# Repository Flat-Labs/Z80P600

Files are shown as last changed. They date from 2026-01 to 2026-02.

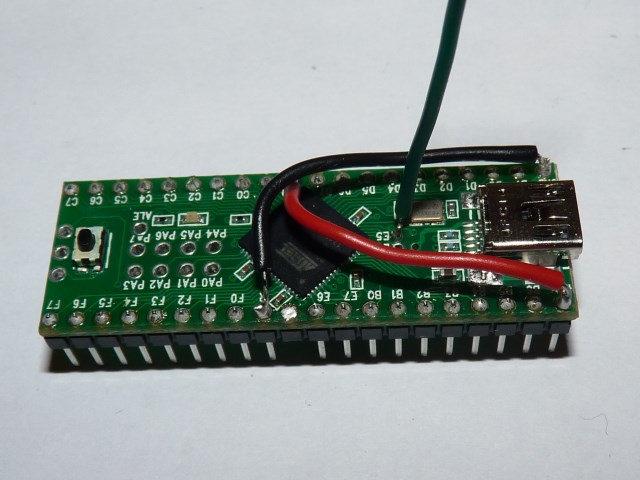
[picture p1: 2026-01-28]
documentation/pictures/4b_solder_wires.jpg

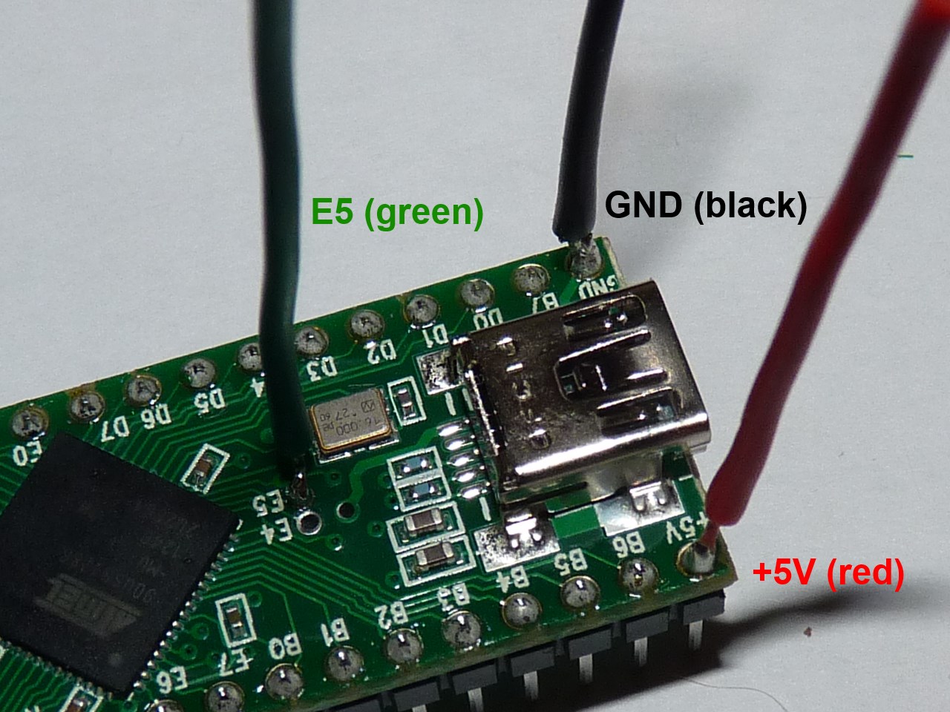
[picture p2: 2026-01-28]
documentation/pictures/2_solder_wires.jpg

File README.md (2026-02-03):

Z80P600
=======

A board and its firmware to replace (and enhance) the Z80 CPU of a SCI Prophet600.

Devised as a tribute to the amazing work of Gligli (http://gligli.github.io/p600fw/) and Imogen (https://github.com/image-et-son/p600fw),
it offers an alternative to Teensy board and its clones. 

Presets, settings, sequences and arpeggios are now stored on a separate F-RAM chip. Thus, all of these won't be lost during upgrades

The firmware functionalities are (almost) absolutely identical to the last Imogen's 2022 version, it only has been adapted to the new board. 
Please refer to the two above addresses for user manuals and informations.
I just added (Beta version) a misc command (From Tape + SEQ1) to wipe the settings out and set them to default . As tuning values are part of the settings, this obviously retunes the synth. 

Compiling and flashing the Firmware
===================================

Requirements:
- AVR-GCC toolchain
- avrdude uploader

For both these pieces of software on Windows, please refer to https://tinusaur.com/guides/avr-gcc-toolchain/.
A very clear and efficient guide to set up the toolchain. I used it with complete success on my windows box.

- python3 (https://www.python.org/downloads/)

- an USBASP programmer with six-pin header, such as this one (https://www.ebay.com/itm/116556456138) (Europe)
  or this one (https://www.ebay.com/itm/382191022734) (US)
  
Compiling:
----------
	> cd firmware
	> make

This will produce p600firmware.hex, which you can flash onto the board.

NOTE: As I'm not used to Github, I was unable to upload the dependence directory (.dep) in a correct manner. Therefore, there is a 'dep' directory in the firmare dir, that should be renamed to .dep for the make process to work.
Sorry for being a newbie here...

Flashing:
---------
1) For the first time.
	- Connect the Z80P600 board to the USBASP programmer (respect the 6-pins header pinout...)
	- Plug the USBASP into the PC
	- First, flash the fuses of the ATMEGA1281 (this has to be done only once, the first time):
	
		> avrdude -c usbasp -p m1281 -U lfuse:w:0x4f:m -U hfuse:w:0xdf:m -U efuse:w:0xf5:m -U lock:w:0xff:m
			
	- and flash the firmware:
	
		> avrdude -c usbasp -p m1281 -U flash:w:"p600firmware.hex":a
	
	To reflash a new version of firmware, only use the above avrdude command, as fuses have already been flashed.

	- Unplug the USBASP programmer of PC, disconnect the board, and plug it in the Z80 socket of P600
	- You're done ;)

2) Sysex upgrades 
	- Sysex upgrades work (From Tape + To Tape while powering on) and can be used to succesively upgrade the firmware through MIDI, provided that an older firmware has already been flashed once.

IMPORTANT NOTE : As the P600 presets, settings, sequences and arpeggios are now stored on a separate F-RAM, uploading (USBASP or sysex) a new firmware won't erase them.
Hence the option to reset the settings, just in case...

Board and PCB
=============

Schematics and PCB have been drawn using Kikad (V9 or above) : https://www.kicad.org/
The prototypes have been made (PCB + assembly) by JLC PCB, and the BOM file includes JLCPCB references for the parts.
The only part that is not included is the 40-pin DIL socket (Mouser ref. https://www.mouser.com/ProductDetail/437-1501064000106161 - gold plated, or https://www.mouser.com/ProductDetail/437-1508064000106101 - tinned), and it has to be hand-soldered.

Everything is working great, but the board LED seems a bit too bright for my taste...
So the R2 resitor value (for the LED) may be increased to something between 470 and 1000 ohms.

License
=======

Everything is under GPL v3 license, except files that have their own license in the header.

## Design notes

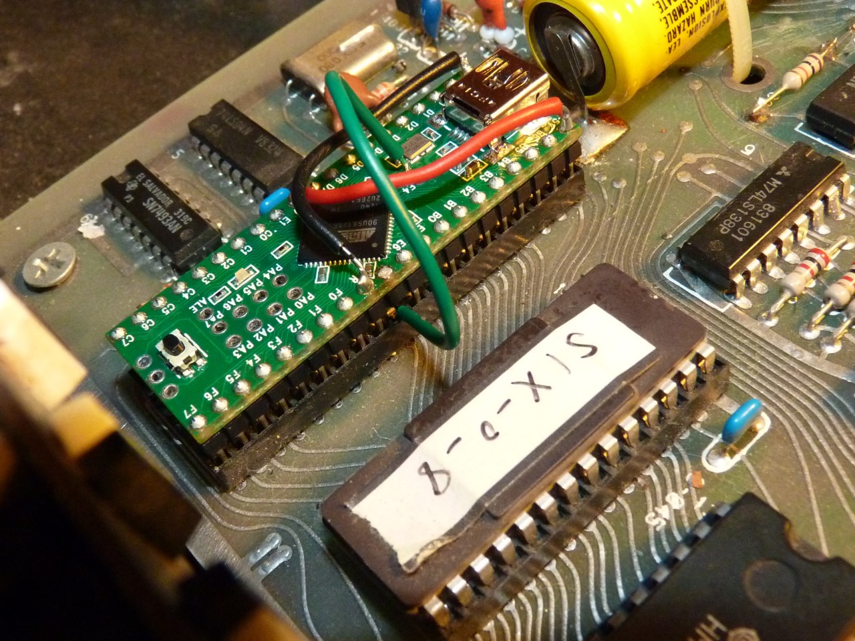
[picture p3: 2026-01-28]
documentation/pictures/6_plug_teensy.jpg

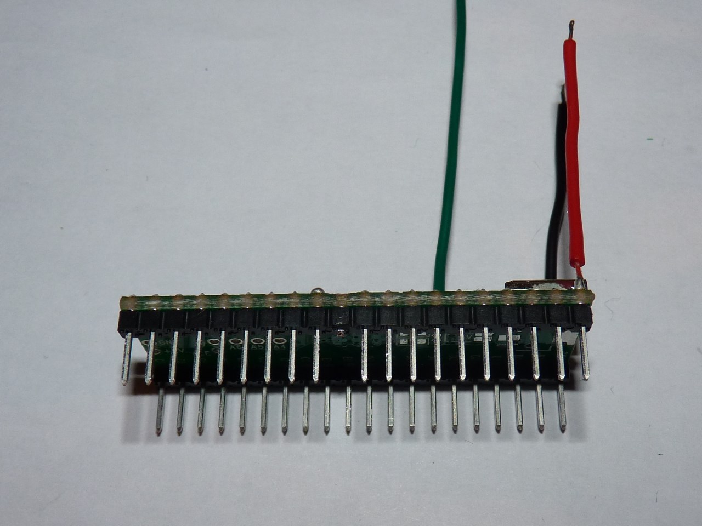
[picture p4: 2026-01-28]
documentation/pictures/3_cut_pin.jpg

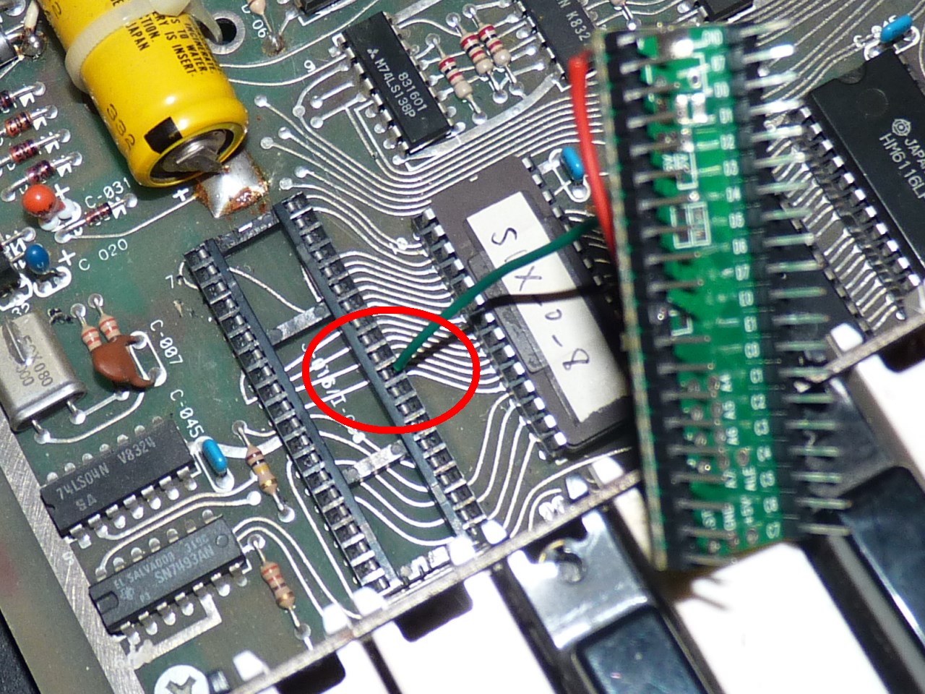
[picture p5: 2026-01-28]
documentation/pictures/5_plug_wire.jpg

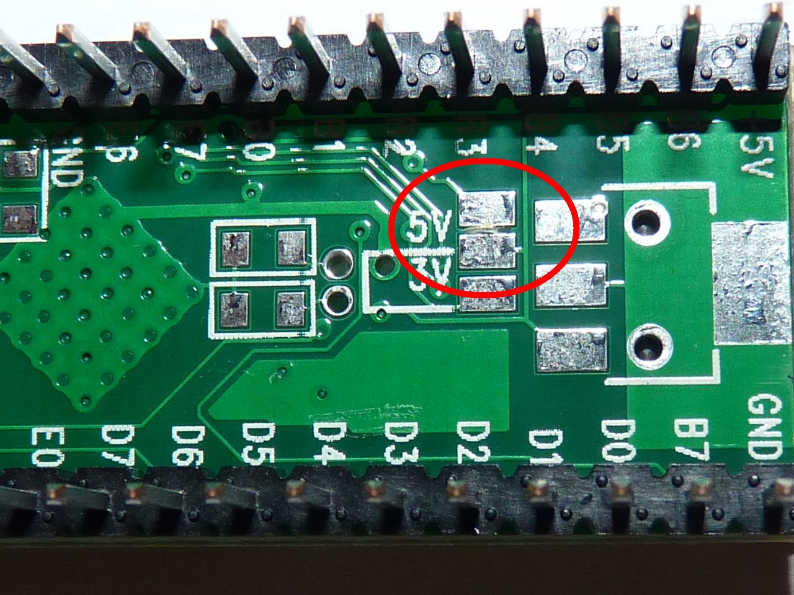
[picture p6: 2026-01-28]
documentation/pictures/1_cut_5v.jpg

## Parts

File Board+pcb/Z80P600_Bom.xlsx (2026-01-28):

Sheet: Feuil1
Reference | Qty | Value | DNP | Footprint
C1,C2,C3,C5,C6,C9,C10,C11,C13 | 9 | 100n |  | Capacitor_SMD:C_0402_1005Metric
C4 | 1 | 10n |  | Capacitor_SMD:C_0402_1005Metric
C7,C8 | 2 | 22p |  | Capacitor_SMD:C_0402_1005Metric
C12 | 1 | 4µ7 |  | Capacitor_SMD:C_0805_2012Metric
D1 | 1 | LED |  | LED_SMD:LED_0603_1608Metric_Pad1.05x0.95mm_HandSolder
J1 | 1 | ISP |  | Connector_PinHeader_2.54mm:PinHeader_2x03_P2.54mm_Vertical
R1 | 1 | 10K |  | Resistor_SMD:R_0402_1005Metric
R2 | 1 | 330 |  | Resistor_SMD:R_0402_1005Metric
SW1 | 1 | SW_MEC_5G |  | Button_Switch_SMD:SW_Push_1P1T-SH_NO_CK_KMR2xxG
U1 | 1 | FM25V05-G |  | Package_SO:SOIC-8_3.9x4.9mm_P1.27mm
U2 | 1 | TPS73633DBV |  | Package_TO_SOT_SMD:SOT-23-5
U3 | 1 | TXU0304RUT |  | Package_DFN_QFN:Texas_R-PUQFN-N12
U4 | 1 | ATmega1281-16A |  | Package_DFN_QFN:QFN-64-1EP_9x9mm_P0.5mm_EP7.65x7.65mm_ThermalVias
Y1 | 1 | 16MHz |  | Crystal:Crystal_SMD_2520-4Pin_2.5x2.0mm

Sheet: Sheet1
Comment | Designator | Footprint | JLCPCB Part #（optional）
100uF | C1 | CAP-SMD_L3.5-W2.8 | C16133
15K | R5,R6 | R0603 | C22809
DC-005-20A_C136744 | DC1 | DC-IN-TH_DC-005-20A | C136744
Header-Female-2.54_1x8 | P2,P3 | HDR-TH_8P-P2.54-V | C27438
K2-1102DP-C4SW-04 | SW1 | KEY-TH_4P-L6.0-W6.0-P4.50-LS6.5 | C110153
ATMEGA328P-PU | U1 | DIP-28_L34.6-W7.3-P2.54-LS10.2-BL | C33901
670688000 | USB1 | USB-B-TH_67068-8000 | C114097

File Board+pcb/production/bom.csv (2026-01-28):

Designator | Footprint | Quantity | Value | LCSC Part #
C1, C10, C11, C13, C2, C3, C5, C6, C9 | 0402 | 9 | 100n
C12 | 0805 | 1 | 4µ7
C4 | 0402 | 1 | 10n
C7, C8 | 0402 | 2 | 22p
D1 | 0603 | 1 | LED
J1 | PinHeader_2x03_P2.54mm_Vertical | 1 | ISP
R1 | 0402 | 1 | 10K
R2 | 0402 | 1 | 330
SW1 | SW_Push_1P1T-SH_NO_CK_KMR2xxG | 1 | SW_MEC_5G
U1 | SOIC-8_3.9x4.9mm_P1.27mm | 1 | FM25V05-G
U2 | SOT-23-5 | 1 | TPS73633DBV
U3 | Texas_R-PUQFN-N12 | 1 | TXU0304RUT
U4 | QFN-64-1EP_9x9mm_P0.5mm_EP7.65x7.65mm_ThermalVias | 1 | ATmega1281-16A
U5 | Z80_DIP-40_SMDSocket | 1 | Z80-Socket
Y1 | Crystal_SMD_2520-4Pin_2.5x2.0mm | 1 | 16MHz

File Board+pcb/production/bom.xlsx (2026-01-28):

Designator | Footprint | Quantity | Value | JLCPCB Part #
C1, C10, C11, C13, C2, C3, C5, C6, C9 | 402 | 9 | 100n | C71687
C12 | 805 | 1 | 4µ7 | C86040
C4 | 402 | 1 | 10n | C60133
C7, C8 | 402 | 2 | 22p | C106203
D1 | 603 | 1 | LED | C3030991
J1 | PinHeader_2x03_P2.54mm_Vertical | 1 | ISP | C225518
R1 | 402 | 1 | 10K | C60489
R2 | 402 | 1 | 330 | C313394
SW1 | SW_Push_1P1T-SH_NO_CK_KMR2xxG | 1 | SW_MEC_5G | C221678
U1 | SOIC-8_3.9x4.9mm_P1.27mm | 1 | FM25V05-G | C66025
U2 | SOT-23-5 | 1 | TPS73633DBV | C28038
U3 | Texas_R-PUQFN-N12 | 1 | TXU0304RUT | C2959768
U4 | QFN-64-1EP_9x9mm_P0.5mm_EP7.65x7.65mm_ThermalVias | 1 | ATmega1281-16A | C1337444
Y1 | Crystal_SMD_2520-4Pin_2.5x2.0mm | 1 | 16MHz | C255948

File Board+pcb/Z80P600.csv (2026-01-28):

Reference | Qty | Value | DNP | Exclude from BOM | Exclude from Board | Footprint | Datasheet
C1,C2,C3,C5,C6,C9,C10,C11,C13 | 9 | 100n |  |  |  | Capacitor_SMD:C_0402_1005Metric | ~
C4 | 1 | 10n |  |  |  | Capacitor_SMD:C_0402_1005Metric | ~
C7,C8 | 2 | 22p |  |  |  | Capacitor_SMD:C_0402_1005Metric | ~
C12 | 1 | 4µ7 |  |  |  | Capacitor_SMD:C_0805_2012Metric | ~
D1 | 1 | LED |  |  |  | LED_SMD:LED_0603_1608Metric_Pad1.05x0.95mm_HandSolder | ~
J1 | 1 | ISP |  |  |  | Connector_PinHeader_2.54mm:PinHeader_2x03_P2.54mm_Vertical | ~
R1 | 1 | 10K |  |  |  | Resistor_SMD:R_0402_1005Metric | ~
R2 | 1 | 330 |  |  |  | Resistor_SMD:R_0402_1005Metric | ~
SW1 | 1 | SW_MEC_5G |  |  |  | Button_Switch_SMD:SW_Push_1P1T-SH_NO_CK_KMR2xxG | ~
U1 | 1 | FM25V05-G |  |  |  | Package_SO:SOIC-8_3.9x4.9mm_P1.27mm | http://www.cypress.com/file/41651/download
U2 | 1 | TPS73633DBV |  |  |  | Package_TO_SOT_SMD:SOT-23-5 | http://www.ti.com/lit/ds/symlink/tps736.pdf
U3 | 1 | TXU0304RUT |  |  |  | Package_DFN_QFN:Texas_R-PUQFN-N12 | TXU0304PWR
U4 | 1 | ATmega1281-16A |  |  |  | Package_DFN_QFN:QFN-64-1EP_9x9mm_P0.5mm_EP7.65x7.65mm_ThermalVias | http://ww1.microchip.com/downloads/en/DeviceDoc/Atmel-2549-8-bit-AVR-Microcontroller-ATmega640-1280-1281-2560-2561_datasheet.pdf
U5 | 1 | Z80-Socket |  | Exclure de la Liste du Matériel |  | Z80P600:Z80_DIP-40_SMDSocket | www.zilog.com/manage_directlink.php?filepath=docs/z80/um0080
Y1 | 1 | 16MHz |  |  |  | Crystal:Crystal_SMD_2520-4Pin_2.5x2.0mm | ~

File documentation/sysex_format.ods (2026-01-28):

Overall SYSEX patch dump request format
Bit count | Value | Description
8 | 0xF0 | SYSEX header
24 | 0x00 0x61 0x16 | My vendor identifier
8 | 0x02 | Command code, “Patch dump request” here
8 | 0-99 | Patch number
8 | 0xF7 | SYSEX footer
Overall SYSEX patch dump format
Bit count | Value | Description
8 | 0xF0 | SYSEX header
24 | 0x00 0x61 0x16 | My vendor identifier
8 | 0x01 | Command code, “Patch dump” here
variable | variable | Encoded raw patch data, truncated to the last nonzero byte
8 | 0xF7 | SYSEX footer
Encoded data format (repeats every 32 bits of raw data)
Bit count | Value | Description
1 | 0 | Padding
7 | variable | Bits 30-24 of raw data (MSB first)
1 | 0 | Padding
7 | variable | Bits 22-16 of raw data (MSB first)
1 | 0 | Padding
7 | variable | Bits 14-8 of raw data (MSB first)
1 | 0 | Padding
7 | variable | Bits 6-0 of raw data (MSB first)
4 | 0 | Padding
1 | variable | Bit 7 of raw data
1 | variable | Bit 15 of raw data
1 | variable | Bit 23 of raw data
1 | variable | Bit 31 of raw data
Raw patch data format
Bit count | Value | Description
8 | 0-99 | Patch number
32 | 0xA5 0x16 0x61 0x00 | My patch format identifier
8 | 0x02 | My patch format version
16 | unsigned, little endian order | Osc A Frequency
16 | unsigned, little endian order | Osc A Volume
16 | unsigned, little endian order | Osc A Pulse Width
16 | unsigned, little endian order | Osc B Frequency
16 | unsigned, little endian order | Osc B Volume
16 | unsigned, little endian order | Osc B Pulse Width
16 | unsigned, centered on half scale, little endian order | Osc B Fine
16 | unsigned, little endian order | Cutoff
16 | unsigned, little endian order | Resonance
16 | unsigned, centered on half scale, little endian order | Filter Envelope Amount
16 | unsigned, little endian order | Filter Release
16 | unsigned, little endian order | Filter Sustain
16 | unsigned, little endian order | Filter Decay
16 | unsigned, little endian order | Filter Attack
16 | unsigned, little endian order | Amp Release
16 | unsigned, little endian order | Amp Sustain
16 | unsigned, little endian order | Amp Decay
16 | unsigned, little endian order | Amp Attack
16 | unsigned, centered on half scale, little endian order | Poly Mod Filter Amount
16 | unsigned, little endian order | Poly Mod Osc B Amount
16 | unsigned, little endian order | LFO Frequency
16 | unsigned, little endian order | LFO Amount
16 | unsigned, little endian order | Glide
16 | unsigned, little endian order | Amp Velocity
16 | unsigned, little endian order | Filter Velocity
7 | 0 | Padding
1 | bit (Off=0,On=1) | Osc A Saw
7 | 0 | Padding
1 | bit | Osc A Triangle
7 | 0 | Padding
1 | bit | Osc A Square
7 | 0 | Padding
1 | bit | Osc B Saw
7 | 0 | Padding
1 | bit | Osc B Triangle
7 | 0 | Padding
1 | bit | Osc B Sqr
7 | 0 | Padding
1 | bit | Sync
7 | 0 | Padding
1 | bit | Poly Mod Oscillator A Destination
7 | 0 | Padding
1 | bit | Poly Mod Filter Destination
5 | 0 | Padding
3 | Pulse=0,Tri=1,Rand=2,Sine=3,Noise=4,Saw=5 | LFO Shape
7 | 0 | Padding
1 | Low=0,High=1 | LFO Speed Range
2 | 0 | Padding
6 | None=0,VCO=1,VCF=2,VCA=4,PW=8,OnlyA=16,OnlyB=32 (combination of those) | LFO Mode Destination
6 | 0 | Padding
2 | None=0,Half=1,Full=2 | Keyboard Filter Tracking
7 | 0 | Padding
1 | Linear=0,Exponential=1 | Filter EG Exponential/Linear
7 | 0 | Padding
1 | Fast=0,Slow=1 | Filter EG Fast/Slow
7 | 0 | Padding
1 | Linear=0,Exponential=1 | Amp EG Exponential/Linear
7 | 0 | Padding
1 | Fast=0,Slow=1 | Amp EG Fast/Slow
7 | 0 | Padding
1 | bit | Unison
6 | 0 | Padding
2 | Last=0,Low=1,High=2 | Assigner Priority Mode
4 | 0 | Padding
4 | 2nd=2,3rd=5,5th=7,Octave=12 | Pitch bender semitones
6 | 0 | Padding
2 | Off=0,VCO=1,VCF=2,Volume=3 | Pitch bender target
5 | 0 | Padding
3 | Min=5,Low=3,High=1,Full=0 | Modulation wheel range
6 | 0 | Padding
2 | Free=0,Semitone=1,Octave=2 | Osc pitch mode
16 | unsigned, little endian order | Modulation delay
16 | unsigned, little endian order | Vibrato frequency
16 | unsigned, little endian order | Vibrato amount
16 | unsigned, little endian order | Unison detune
16 | unsigned, little endian order | Arpeggiator/sequencer clock
7 | 0 | Padding
1 | LFO=0,Vibrato=1 | Modulation wheel target
8 | 0 | Padding
6*8 | 6 offsets in semitones to the lowest chord note, 0xFF padded. Eg: 6 times 0x00 for unison, 0x00 plus 5 times 0xFF for mono mode. | Unison track pattern

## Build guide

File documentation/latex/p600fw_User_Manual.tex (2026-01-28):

%\documentclass[draft,landscape, 11pt, oneside]{report}
\documentclass[landscape, 11pt, oneside, twoside]{report}
\usepackage[a4paper, left=1cm, right=1cm, top=2.5cm]{geometry}
\usepackage{lmodern}
\usepackage{hyperref}
\usepackage{titlesec}
\usepackage{scrextend}
\usepackage{array}
\usepackage{ProphetPanel}
\usepackage{fontspec}
\usepackage[T1]{fontenc}
\usepackage{longtable}
\usepackage{ProphetTerms}
\usepackage{float}
\usepackage{setspace}
%\usepackage[inline]{showlabels}
\setmainfont[
 BoldFont={FiraSans-Bold}, 
 ItalicFont={FiraSans-Italic},
 ]{FiraSans}
\setlength{\parindent}{0pt}
\setlength{\parskip}{1em}
\setlength{\evensidemargin}{0cm}
\setlength{\oddsidemargin}{2cm}
\setlength{\paperheight}{210mm}
\setlength{\paperwidth}{297mm}
\setlength{\textwidth}{22cm}
\setlength{\footskip}{2.5cm}
%\input{defined_terms.tex}
\newenvironment{flowtext}{\addmargin[0cm]{0cm}}{\endaddmargin} % standard text width (reduced for layout)
\newcommand{\pp}[1]{} % patch parameter
\newcommand{\app}[2]{} % additional patch parameter, 1: number, 2: name

%%\title{[DRAFT] User Manual for the GliGli upgraded Prophet-600}
%%\pagestyle{myheadings}\markright{[DRAFT] User Manual for the GliGli upgraded Prophet-600}
%%\makeatletter
%%\renewcommand\chapter{\pagestyle{myheadings}\markright{[DRAFT] User Manual for the GliGli upgraded Prophet-600}\global\@topnum\z@\@afterindentfalse\secdef\@chapter\@schapter}
%%\makeatother
\titleformat{\chapter}[display]{\LARGE\bfseries}{}{0.0cm}{}
\titlespacing{\chapter}{0pt}{*0}{*0}
\titlespacing{\section}{0pt}{*0}{*0}

%%
%% Document Start
%%

\begin{document}

\raggedbottom
\singlespacing

\begin{titlepage}
\pagenumbering{gobble}

% this it the title "Prophet-600"
  \begin{tikzpicture}[scale=0.8]
    \begin{scope}[xslant=0.1]
        \SSGBit[1.5cm]{0,0}{12567}
        \SSGBit[1.5cm]{2.5cm,0}{57}
        \SSGBit[1.5cm]{5cm,0}{5734}
        \SSGBit[1.5cm]{7.5,0}{12567}
        \SSGBit[1.5cm]{10cm,0}{3567}
        \SSGBit[1.5cm]{12.5cm,0}{14567}
        \SSGBit[1.5cm]{15cm,0}{4567}
        \SSGBit[1.5cm]{17.5cm,0}{7}
        \SSGBit[1.5cm]{20cm,0}{134567}
        \SSGBit[1.5cm]{22.5cm,0}{123456}
        \SSGBit[1.5cm]{25cm,0}{123456}
      \end{scope}
  \end{tikzpicture}

  \vspace{1cm}

  \Huge
  User Manual \vspace{0.4cm} \\
  \Large
  Edition: version v2022 (8.8.2022) \vspace{0.3cm}\\
  Firmware version: GliGli \version by imogen\vspace{0.3cm}\\
  Editor / author: imogen / image-et-son 
  \normalsize

\end{titlepage}

\pagebreak
\pagebreak

%\maketitle
\tableofcontents

\pagestyle{myheadings}\markright{Prophet-600 \version User Manual }
\makeatletter
\renewcommand\chapter{\pagestyle{myheadings}\markright{Prophet-600 \version User Manual}\global\@topnum\z@\@afterindentfalse\secdef\@chapter\@schapter}
\makeatother

\pagebreak
\chapter{Introduction to the GliGli Prophet-600 Firmware Upgrade}

\pagenumbering{arabic}
\setcounter{page}{1}

\begin{flowtext}

The original Sequential Circuits Prophet-600 from around 1982 is run by a Zilog Z80 processor. This processor (and the firmware written for it) is pushed beyond its limits for computing and applying the voltages, for scanning user inputs and managing MIDI events. The necessary compromises made the instrument steppy, glitchy and non-responsive. That is a pity, because the basic synth voice hardware of the Prophet-600 is good: unlike DCO synths which became popular and affordable at the time, the Prophet-600 is a 6 voice analog synthesizer driven by 2 voltage controlled oscillators (VCOs) and a 24db low pass filter per voice, all implemented using the renowned Curtis chips \cite{curtis}. The hardware also provides hard sync, frequency modulation and even modulation of cut-off by VCO. It is very versatile. The shortcomings of the original Prophet-600 were due only to the unfortunate circumstance that the selected and commonly available micro-processors at the time were not powerful enough for the Prophet-600. So the idea to make use of a more modern processor 30 years later was interesting. Around 2013 GliGli \cite{gligli} started reverse engineering the original firmware for the Z80 and found that the Z80 can be replaced by a (more) modern Teensy++ 2.0 USB programmable microprocessor \cite{teensy} (with some hardware modifications). This was the start of what is now know as the \textit{Prophet-600 GliGli firmware upgrade}. GliGli describes his motivation as follows:

\begin{addmargin}[2cm]{1cm}

\textit{I love vintage analog synthesizers, and to be honest, my dream synth would be a Prophet-5, but when I heard what the Prophet-600 was capable of tone wise, I immediately thought its major weaknesses -- the lousy computer part, software envelopes and LFO -- could become its strength with a remake; basically the whole internal synth in voltage-controlled from a nice 14bit DAC, so with a fast modern micro controller, it could become awesome, maybe even better than a Prophet-5!}

\end{addmargin}

There are various modifications and modern CPU "implants" for some vintage analog synthesizers. Since the Teensy++ 2.0 board fits in to the same 2x20 pin standard socket of the Z80, the decisive advantage of the GliGli approach is that it is an easy-to-install and non-destructive firmware drop-in replacement\footnote{There are two versions of the Prophet-600. One has the Z80 on a socket. In this case replacement is truly "drop-in". The other version has the Z80 soldered to the circuit board. In this case the Z80 needs to be removed and a socket has to be soldered in its place first.}. It is completely safe to try out the Teensy++ 2.0 upgrade because one can always remove the board and restore the Z80 without technical expertise or training. 

The Teensy++ 2.0 offers completely new possibilities. Just looking at specs: the Z80 version of the Prophet-600 ran at 4 MHz while the ATMEL processor on the Teensy board is operated at 16 MHz. Also, the on-board flash memory provides much better storage and firmware handling possibilities compared to the EPROM which the Z80 uses. The firmware does not rely on a battery for keeping patch data in memory. With the replacement the obvious limitations of the original Prophet-600 could be overcome - but more than that, it opened the possibility for new and for enhanced features. 

Developing the software was a major effort with low-level functions and basic hardware communication at the core, e.g. instruction to set voltages to the electronic components, MIDI (interrupt) implementation, multiplexer operations and DAC operations. On top of this there is the "musical" part of coding such as envelopes, LFOs, modulations and sequencing functions as well as UI functions. Many people have contributed, most probably out of curiosity and passion for synthesizers and driven by the excitement that such a project could not only be conjured up but also be implemented and brought to life. 

The first stable version of the firmware upgrade was version 2.0 in 2014. An intermediate release (or at least something close to a release) version 2.1 Release Candidate 3 (2.1 RC3) has been available from September 5th 2015 on GliGli's webpages \cite{gligli}. The latest release version \version is the result of continued development between September 2021 and March 2022. It is meant as a celebration and revival of the original idea and it provides various new features and also significant improvements in core functions. The latest firmware version can be found on the project page\cite{newversion}.

While there is a realistic backlog of additional ideas to come in the future, there is a clear end of Prophet-600 upgrade story in sight because of ultimate hardware limitations. Firstly, PJRC (the manufacturer of the Teensy boards) has stopped producing the Teensy++ 2.0 board, so that it has become difficult to find them. Secondly, after extensive performance testing in the latest firmware developments efforts, it has become clear that the performance (smoothness and responsiveness of controls, timely and accurate processing of information) is finally limited by the built-in hardware, in particular the DAC (limited by voltage rise times) and multiplexer (limited by switching times). 

If you own a Teensy++ 2.0 upgraded Prophet-600 you can still enjoy some exciting new developments. The following is a compact summary of the improved and the new features. The manual generally refers to the latest version \version. Differences between versions are marked or commented in the text for your information. Share the passion for analog synthesizers with the Prophet-600 upgrade story!  

\begin{flushright}
  \textit{imogen / image-et-son}
\end{flushright}

\pagebreak
\section{What you can expect from the Firmware Upgrade}

\textbf{General features compared to the original Z80 version}
  
\begin{itemize}
  \setlength\itemsep{0cm}
  \item Greater resolution of many of the sound parameters with an improved refresh rate that makes the instrument much more responsive, again improved in \version using a dynamic scheme for reading user controls.
  \item Faster and smoother ADSR envelopes with support for two speed regimes (slow, fast) and two shapes (linear, exponential). The latest version \version has new linear shapes which were inspired by Prophet-5 rev 1/2 envelopes and designed to be more organic and musical than the former linear shapes.
  \item Positive and negative envelope amount settings for filter and poly-mod 
  \item A new LFO function generator with a wider frequency range from one cycle every 20 seconds to about 60Hz
  \item Assignable, random and up/down arpeggiator, optionally sync-able to external MIDI and analog clock
  \item Multiple note assignment modes including last/low/high note priority
  \item Full MIDI In control including amplitude and filter velocity sensitivity with an external keyboard controller, continuous controllers (CC) of all sound parameters, program change (PC) to choose current preset
  \item A dedicated vibrato which can be controlled by the modulation wheel
  \item Unison chord mode
  \item Four new LFO waveforms in addition to the original triangle and square including sine, random stepped, noise (like on the original Prophet-5, but non-periodic) and sawtooth (ramp up)
  \item Mix overdrive which now allows the output from both oscillators to drive the mix VCAs A and B harder as well as the Curtis 4 pole filter resulting in new sonic possibilities
  \item Pitch Wheel interval selection of plus/minus one octave, a whole tone, a minor third and a fifth
  \item Pitch Wheel reassignment to the VCF and Volume or off   
  \item Modulation wheel intensity setting in four steps, with a smooth (exponential) action in the latest version \version
  \item A new and improved tuning procedure
  \item Octave, chromatic and free oscillator course pitch control, with different options for oscillators A and B in the latest version \version
  \item Debounce feature that prevents unintended re-triggering caused by the old keyboard
\end{itemize}

\textbf{Specific features from version 2.1 RC3 onwards}
  
\begin{itemize}
  \setlength\itemsep{0cm}
  \item Polyphonic step sequencer
  \item Per note tuning
  \item Improved UI, introducing display of -50...50 range for bipolar dials and center deadband for better handling  
  \item VCF limit option
  \item Maintenance mode / adjustment scaling
  \item Vintage (spread) function for voice variations in tune and envelopes, re-designed as a continuous parameter in version \version which can even be controlled by MIDI CC   
  \item Support for pedal to sustain notes and to hold chords (in unison)
  \item On-the-fly transpose function for arpeggiator and sequencer
\end{itemize}

\textbf{Features with version \version}
  
\begin{itemize}
  \setlength\itemsep{0cm}
  \item Smoother and more responsive actions of all controls due to dynamic scanning scheme 
  \item Softer (exponential) action of LFO control (frequency and amount) to provide more travel for common "musical" value ranges
  \item Super accurate oscillator B fine tuning using a slow mid region
  \item Improved envelope shapes inspired by the Prophet-5 rev 1/2 shapes, replacing the linear shape in versions 2.0 and 2.1 RC3.  
  \item Revised and more intuitive organisation of menu parameters in groups with corresponding "cheat sheet"
  \item A new UI concept with pick-me-up behaviour, in order to avoid discontinuous value changes and to make the differences between panel and internal values transparent 
  \item Switchable panel layout with choices: Mix / Glide (Sequential Circuits / SCI layout)and Volume A / Volume B (synthgraphics supported GliGli layout) 
  \item Flexible envelope routing allowing the poly-mod to be modulated by either envelope generator
  \item Ability to sync the LFO to the arpeggiator and sequencer
  \item Better MIDI integration possibilities through new local off mode and MIDI input into sequencer and arpeggiator
  \item Improved and protected patch management via MIDI, supporting single patch dump and loading MIDI patch to active controls 
  \item Changed arpeggiator patterns: omitting the top and bottom note repeat in the U/D arpeggiator pattern and removing note repeats in the random pattern
  \item Support for adjusting the external CV input amount
  \item Vibrato target VCA
\end{itemize}

In addition to this, several more technical / advanced changes were made such as the option to switch between "round robin" and "first" voice assign logic, the ability toggle a pulse width sync bug which has been introduced in the version 2.0 (and kept for compatibility in version 2.1 RC3), changes to remove the interference  of internal and external (MIDI) pitch bend by adding the two (as in the original SCI firmware), stabilization of the external analog clock input.

\section{On compatibility for those upgrading from 2.0 and 2.1 RC3}

You can upgrade the firmware by SysEx or by directly loading the firmware onto the Teensy++ 2.0 board via USB (see section \ref{fwupgrade}). When upgrading by SysEx, both patch data and settings are preserved. Backward compatibility is ensured, i.e. patches created in prior firmware version (including Z80) still work properly on new firmware versions. Note that as a general principle, before performing any upgrade the safekeeping of patches is not only best practice but also strongly recommended. The following contains some remarks which are relevant if you are upgrading to version \version from version 2.0 or 2.1 RC3.

\textbf{Panel}: If you have a synthgraphics overlay, there are some minor changes (also reflected in the figures in this manual). Firstly, the layout of the menu parameters has been changed - these are now grouped in themes and since there are more parameters, selecting a parameter requires three presses in some cases. So the "cheat sheet" that some users have attached to the left of the number pad is not correct any more. Secondly (and less significant), what was formerly the "amplitude envelope" is now referred to more generally as the "2nd envelope". There are additional envelope routing options so that this envelope has a more generalized role. 

\textbf{Vintage / Spread}: With 2.1 RC3 a "spread" switch was introduced as part of the global settings (not part of the patch). With version \version this has been removed from the settings and has been reintroduced as the patch parameter \textit{vintage spread}. It serves the same purpose, but it can be controlled continuously and it is more randomized than the former spread switch for more realistic results.

\textbf{Detune}: The unison detune has undergone a scaling re-design in version \version: the detune is now less pronounced at higher frequencies. This has been done to achieve the same subjective detuning effect across the whole frequency range. This is a change to the sound of the instrument and depending on how you use detune, your detuned unison patches may sound slightly different at higher registers compared to prior firmware versions. The idea is of course, that this is an agreeable change for everybody.

\textbf{Arpeggiator}: The arpeggiator patterns up/down and random have been changed in version \version

\textbf{MIDI CC}: Due to the change in menu parameters (obsolete parameters) and subsequent reshuffling (re-designation of the CC values for the legacy LFO frequency range), the specification of MIDI CC has changed slightly. As a result of rescaling of parameters the MIDI CC value to action has changed for LFO and vibrato frequencies and LFO and vibrato amounts as well as decay and release times of envelopes with linear shape. When loading older patches, the changes are taken into account to ensure compatibility.

\textbf{Envelopes}: The linear envelope shape has been revised in version \version. It is now a linear shape with an exponential tail (i.e. a softer roll-off) for decay and release. It was a deliberate decision to replace the linear shape altogether. Note that the smooth roll-off required a rescaling of the envelope decay and release controls for linear shapes. When loading older patches, the changes are taken into account to ensure compatibility: the effective decay and release times are preserved. However, the application of MIDI CC values is different, so if you are controlling sound by MIDI CC you may need to make adjustments.

\section{Credits and license}

The firmware upgrade project is an open source project. The GliGli code base (up to and including version 2.1 RC3) can be found in \cite{gligli} and the new code base of the latest development can be found in \cite{imogen}. When I first drafted this manual I hoped to put together a credits section by assembling a fair and comprehensive list of contributors. I have given up. There was no one who could, with authority, list and assess what came from where and who added what. From my research I can say that a \textbf{lot} of people have contributed and some have obviously spent considerable time to make this software as useful and consistent as possible. 

Let me just give you some highlights and a brief roundup. First, I think that the original 77 page technical documentation of the Prophet-600 by Stanley Jungleib \cite{p600siservicemanual} is great and such  documentation is both helpful and more than one can expect. Then there is an elaborate blog "Prophet-600 Spirit" by \textit{minisystem} \cite{p600spirit} which is legacy by now but still available. It contains a lot more technical information, Prophet-600 hardware related ground work, I would call it. I had the impression that it also helped the project. The contributors to the actual code can be obtained from the submit history of the code base on Github \cite{imogen}. Apart from GliGli (obviously) I found \textit{snickell} and \textit{Ricard Wanderlof} with many commits, although I haven't taken the time to disseminate their contributions in detail. Then there is the community, especially (but certainly not exclusively) on Gearspace (a common community platform for people to discuss music gear, not so long ago also known as Gearslutz): testing, giving feedback, spreading the word, supporting the project by appreciation and enthusiasm. Since I started picking up the development in November 2021 I joined up with a group of supporters and musicians loosely bound together by a forum thread on Gearspace. A number of active users have been especially helpful in prioritizing features, testing and proof reading. I neither want to list all of them, nor single someone out. Let me just say that developing the new envelopes and experimenting with different and sometimes really tricky aspects of the Prophet-600 hardware (e.g. multiplexers) would have been a lot less fun (and in parts even impossible) without an active community and dedicated co-workers.  

This user manual contains some texts and snippets written by other people. I compiled, merged, extended and in some case corrected the available information to an extent that makes it near impossible to trace everything back to its origins, let alone put in proper references. I just assume that all consent to the usage of their words. The overwhelming part of the text and the graphics are new.

The firmware  is under GPL v3 license, except files / libraries / other open source components that have their own license in the header. The usage of the software and related documentation (including descriptions and references to descriptions for making modifications to hardware) are understood to be at the user's own risk. The firmware program is distributed in the hope that it will be useful, but WITHOUT ANY WARRANTY; without even the implied warranty of MERCHANTABILITY or FITNESS FOR A PARTICULAR PURPOSE. See the GNU General Public License for more details.

\end{flowtext}

\pagebreak

\chapter{Finding your way around your new  Prophet-600}    

\begin{flowtext}

The different controls and interfaces of the Prophet-600 are shown schematically below. Throughout the document the corresponding nomenclature is used. In the original GliGli firmware upgrade the dials for oscillator A vs. B mix had been replaced by separate dials for oscillator A volume and oscillator B volume, at the expense of demoting the glide amount to a menu parameter. In the newest firmware version you have the choice to either use the \textit{GliGli} layout or the original \textit{Sequential Circuits (SCI)} layout. For more details on how to change the panel and on the parameters in each case see section \ref{panelswitch}.

\begin{samepage}
  \textbf{GliGli panel layout (like synthgraphics overlay)}
  
  \nopagebreak
  \scalebox{0.2}{
    \begin{tikzpicture}[scale=0.8]
      \input{full_panel_gligli.tex}
    \end{tikzpicture}
  }
\end{samepage}

\begin{samepage}

  \textbf{Sequential Circuits panel layout}
  
  \nopagebreak
  \scalebox{0.2}{
    \begin{tikzpicture}[scale=0.8]
      \input{full_panel_sci.tex}
    \end{tikzpicture}
  }
\end{samepage}

The following sections contain a brief explanation of the controls and interfaces: the \textbf{Rear}, \textbf{Data Pad}, \textbf{Panel} (with sub-panels), \textbf{Performance Section} and \textbf{Keyboard}.

\section{Data Pad and basic operation}\label{datapad}

The \datapad consists of the \display (2 two digit 7 segment display with one dot\footnote{The were good ideas for using a second display dot to make the UI more sophisticated, but - unfortunately - even though the display has the second dot, the Prophet-600 hardware supports control of only one dot.}), the \termnumberpad, the \funcbuttons and the \datadial. 

\textbf{Function Buttons}

The block of 9 \funcbuttons is the main control from where you activate and toggle the operation modes and functions of the Prophet-600. This block consists of an upper part (controlling essential functions) and a block of buttons relevant for the sequencer and arpeggiator, as shown below. (The \record button has a function of both.)

\scalebox{0.4}{
  \begin{tikzpicture}[scale=0.8]
  \node[font=\fontsize{26}{22}\selectfont, align=right, outer sep=0.5mm, anchor = west, text width=10cm] at (0cm,12cm) {Upper block of Function Buttons:};
    \upperbuttons{15cm,7cm}{P}{}
  \node[font=\fontsize{26}{22}\selectfont, align=right, outer sep=0.5mm, anchor = west, text width=10cm] at (30cm,12cm) {Buttons relevant for sequencer and arpeggiator:};
    \arpsqbuttons{45cm, 9cm}{R1}{1}
  \end{tikzpicture}
}

The \funcbuttons have LEDs which can be off, be on solid and on blinking. In the entire document the following convention for representing the button LED status off / on / blinking is used.

\scalebox{0.4}{
  \begin{tikzpicture}[scale=0.8]
  \node[font=\fontsize{26}{22}\selectfont, align=left, outer sep=0.5mm, anchor = west] at (0cm,2.5cm) {LED \\ Status:};
  \prophetledbutton[1cm]{10cm, 2.5cm}{RECORD}{R}{}{R}
  \node[font=\fontsize{26}{22}\selectfont, align=left, outer sep=0.5mm, anchor = west] at (11.5cm,2.5cm) {= LED on solid};
  \prophetledbutton[1cm]{25cm, 2.5cm}{RECORD}{R}{R}{R}
  \node[font=\fontsize{26}{22}\selectfont, align=left, outer sep=0.5mm, anchor = west] at (26.5cm,2.5cm) {= LED on blinking};
  \prophetledbutton[1cm]{40cm, 2.5cm}{RECORD}{}{}{R}
  \node[font=\fontsize{26}{22}\selectfont, align=left, outer sep=0.5mm, anchor = west] at (41.5cm,2.5cm) {= LED off};
  \end{tikzpicture}
}

The different functions of the buttons are described in the general modes description in section \ref{uimode}, and throughout the chapter \ref{function} in the context of specific functions in which they are used.

\textbf{Number Pad}

This pad has three usages depending on mode and selected functions:

\begin{itemize}
  \item Selecting a patch number from one of the internal 100 patch storage slots to load in \presetpatch  (see section \ref{uimode})
  \item Selecting a patch number for storing a patch to one of the internal 100 patch storage slots in \storagemode (see section \ref{loadstorepatches})
  \item Selecting a patch number to export a patch as MIDI SysEx in \patchmgmt (see section \ref{patchmgmt})
  \item Selecting a function / setting in \shiftmode and \shiftlock (see miscellaneous settings below and overview in section \ref{settingsref})  
  \item Selecting a parameter in the additional patch parameter menu (see section \ref{app}) in \presetpanel and in \livemode
\end{itemize} 

\pagebreak

\textbf{Display}

\input{display.tex}

\pagebreak

\textbf{Preset panel mode, live mode and additional patch parameters menu}\label{app}

The Prophet-600 operates in two modes, \presetmode and \livemode, see section \ref{uimode}. The mode of operation determines what the display shows and what functions are invoked when you press the number pad buttons, as shown in the table below.

\scalebox{0.4}{
  \begin{tikzpicture}[scale=0.8]
    \node[font=\fontsize{26}{22}\selectfont, align=left, outer sep=0.5mm, anchor = west] at (-8cm,13cm) {Basic modes:};

    \draw[line width=1pt]++(-6cm,-7.5cm)--++(55cm,0cm);  
    \draw[line width=1pt]++(-6cm,-5cm)--++(55cm,0cm);  
    \draw[line width=1pt]++(-6cm,-3cm)--++(55cm,0cm);  
    \draw[line width=1pt]++(-6cm,-1cm)--++(55cm,0cm);  
    \draw[line width=1pt]++(-6cm,9.5cm)--++(55cm,0cm);  

    \node[font=\fontsize{26}{22}\selectfont, align=left, outer sep=0.0mm, anchor = west, text width=12cm] at (-6cm,5cm) {LED};
    \node[font=\fontsize{26}{22}\selectfont, align=left, outer sep=0.0mm, anchor = west, text width=12cm] at (-6cm,-2cm) {Display};
    \node[font=\fontsize{26}{22}\selectfont, align=left, outer sep=0.0mm, anchor = west, text width=12cm] at (-6cm,-4cm) {Number pad};
    \node[font=\fontsize{26}{22}\selectfont, align=left, outer sep=0.0mm, anchor = west, text width=12cm] at (-6cm,-6.5cm) {Enter / leave};

    \node[font=\fontsize{26}{22}\selectfont, outer sep=0.0mm, anchor = south west, text centered, text width=12cm] at (4cm,10cm) {\livemode};
    \node[font=\fontsize{26}{22}\selectfont, outer sep=0.0mm, anchor = south west, text centered, text width=12cm] at (19.2cm,10cm) {\presetpatch};
    \node[font=\fontsize{26}{22}\selectfont, outer sep=0.0mm, anchor = south west, text centered, text width=12cm] at (34.2cm,10cm) {\presetpanel};

    \node[font=\fontsize{18}{22}\selectfont, outer sep=0.0mm, anchor = west, text centered, text width=12cm] at (4cm,-2cm) {Parameter values};
    \node[font=\fontsize{18}{22}\selectfont, outer sep=0.0mm, anchor = west, text centered, text width=12cm] at (19.2cm,-2cm) {Patch number};
    \node[font=\fontsize{18}{22}\selectfont, outer sep=0.0mm, anchor = west, text centered, text width=12cm] at (34.4cm,-2cm) {Parameter values};

    \node[font=\fontsize{18}{22}\selectfont, outer sep=0.0mm, anchor = west, text centered, text width=12cm] at (4cm,-4cm) {Select add. parameter};
    \node[font=\fontsize{18}{22}\selectfont, outer sep=0.0mm, anchor = west, text centered, text width=12cm] at (19.2cm,-4cm) {Select patch};
    \node[font=\fontsize{18}{22}\selectfont, outer sep=0.0mm, anchor = west, text centered, text width=12cm] at (34.4cm,-4cm) {Select add. parameter};

    \node[font=\fontsize{18}{22}\selectfont, outer sep=0.0mm, anchor = west, text centered, text width=12cm] at (4cm,-6.25cm) {From \preset using \preset button};
    \node[font=\fontsize{18}{22}\selectfont, outer sep=0.0mm, anchor = west, text centered, text width=12cm] at (19.2cm,-6.25cm) {From \livemode using \preset, from \presetpanel mode using \totape};
    \node[font=\fontsize{18}{22}\selectfont, outer sep=0.0mm, anchor = west, text centered, text width=12cm] at (34.4cm,-6.25cm) {From \presetpatch mode using \totape};

    \upperbuttons{6cm, -0.5cm}{}{}   
    \upperbuttons{21cm, -0.5cm}{P}{}   
    \upperbuttons{36cm, -0.5cm}{PT}{}   
    \draw[line width=1pt]++(4cm,-7.5cm)--++(0cm,19cm);  
    \draw[line width=1pt]++(19.2cm,-7.5cm)--++(0cm,19cm);  
    \draw[line width=1pt]++(34.4cm,-7.5cm)--++(0cm,19cm);  
  \end{tikzpicture}
}

The following section describes how patch parameters are accessed and modified in live mode and in \presetpanel. Patch parameters are - by definition - stored, exported and loaded per patch. Most patch parameters can be controlled using dials and switches on the panel (see section \ref{panel}). With the firmware upgrade the Prophet-600 provides a range of \textbf{Additional Patch Parameters}. There are \textit{continuous} parameters (numeric) and \textit{stepped} parameters (select options). Changing these parameters can only be done in \presetpanel or in \livemode. You must select the parameter first and then change the value using the \datadial. A parameter is selected by pressing the buttons 0...9 on the \termnumberpad (or pressing them twice or in some cases three times). If you select a new parameter, the respective parameter name is scrolled through the display. The display then shows the current value. Numeric values are shown permanently and choice settings are scrolled through the display. 

Each parameter is explained in the respective functional context in the next chapter. For a quick reference of additional patch parameters please see section \ref{patchref}. 

Note 1: The parameter accessed using the number 0 is an exception. The parameter \clock controls the internal sequencer and arpeggiator speed or external clock divide and this speed is stored as an instrument setting (see next section) and not as a patch parameter. For details on \clock see \ref{sync}.

\textbf{Shift mode and miscellaneous settings}

The \miscsett are patch independent instrument settings and functions. These settings are stored and re-loaded after a power cycle. The miscellaneous settings are accessed via the \termnumberpad in \shiftmode. To activate this mode either hold down the button \fromtape while selecting one of the additional functions or double press \fromtape to enter \shiftlock (permanent shift) indicated by a blinking \fromtape LED. To exit the mode push the button again. 

In \shiftmode the numbers 0...9 on the \termnumberpad as well as some of the function buttons let you access the \miscsett. The settings are edited by pressing the respective buttons repeatedly to cycle through values or to initiate actions. The first time a button is pressed the display scrolls the current value or mode. Pressing the same number key again cycles through the values of that setting or confirms a certain action or mode change. 

Some important functions which you access in \shiftmode and \shiftlock are ...
\begin{itemize}
  \item ... the numbers 0...9 access MIDI setup, voice (de-)activation, panel layout, pitch bender calibration, panel layout switch, etc. 
  \item ... the keys on the keyboard are used to set the keyboard transposition (see section \ref{transposition}) 
  \item ... the \tune button activates the \pernote  (see section \ref{tuning}).
  \item ... pressing the \record button activates the \patchmgmt (see section \ref{patchmgmt})
  \item ... pressing the \preset (and confirmation) loads the default patch (see section \ref{defaultpatch})
\end{itemize}

The list of miscellaneous settings can be found in section \ref{settingsref}. Each setting is explained in the respective functional context in the chapter \ref{function} and in the chapter \ref{maintenance} on instrument setup tasks.

\section{Panel}\label{panel}

Two slightly different panel layouts are supported. In \textit{SCI} layout the panel is organized in 6 sub-panels, 3 additional patch controls (\unison, \mixer and \glidepot) plus two global controls, \mastertune and \mastervol. In \textit{GliGli} layout the panel is organized in 7 sub-panels (an additional mixer sub-panel), the patch parameter \unison and the two global controls \mastertune and \mastervol. 

\begin{itemize}
  \item Poly-Mod sub-panel (see section \ref{polymod})
  \item LFO sub-panel (see section \ref{lfo})
  \item Oscillator A sub-panel (see section \ref{osc})
  \item Oscillator B sub-panel (see section \ref{osc})
  \item Mixer sub-panel (in GliGli panel layout only, see section \ref{osc}).  
  \item Filter sub-panel (see section \ref{filter} and \ref{envelopes}) 
  \item 2nd Envelope sub-panel (see section \ref{envelopes})
  \item Unison switch (see section \ref{poly-unison-voice})
  \item Mix dial (in Sequential Circuits panel layout only, see section \ref{osc})
  \item Glide dial (in Sequential Circuits panel layout only, see section \ref{glide})
\end{itemize}

These controls are all patch parameters, which means they are stored, loaded, imported and exported with a patch. The panel controls \mastertune and \mastervol to the very right of the panel are not part of the patch. These controls are always applied as they are. They are meant to adjust the instrument to the performance environment (e.g. spontaneous tuning to a band/ensemble and adjustment of the volume). Also, you can always reliably start the instrument with volume turned to zero.

\section{Keyboard and performance section}

Without modifications, the Prophet-600 comes with a non-weighted, 5 octave (61 key) keyboard. The keyboard does not support touch sensitivity (although the upgraded Prophet-600 supports velocity sensitivity for amplitude and filter via MIDI, see section \ref{velocity}). Apart from playing, the keyboard is used for arpeggiator and sequencer input (see section \ref{seq}) and for transposition (see section \ref{transposition}). 

The Prophet-600 offers a \pitchbender (unfortunately without a spring mechanism) and a \modwheel. The mid position of \pitchbender can be calibrated and there are several different bend targets to choose from, see section section \ref{pitchbend}. You can adjust the effect strength or action profile of the modulation wheel, and you choose if it should modulate the LFO or the vibrato, see section \ref{modwheel}.

\section{Rear, inputs and output}

\input{rear.tex}

\section{The concept}

With the clearly laid out panel controls the Prophet-600 is both, a hands-on performance instrument and a sound sculpting synthesizer at the same time. The upgrade preserves that basic character. The controls on the panel have largely the same function as in original. 

However, the new functionalities of the upgrade required additional parameters and these had to be placed in new hidden menus. This has obvious disadvantages. Diving into menus interrupts the work flow. It is abstract and unsatisfying. It is only acceptable for parameters which are rarely used and certainly not suited for live tweaking. 

Another important aspect is the preservation of the general user interface concept. In particular, for each function there should be a unique way to do it, not a mix of say, dials and menus. This is one reason why the upgrade also contains "only" one LFO and two envelopes even though one might have added more with the new processor. This corresponds to the layout of the Prophet-600 and anything more would have meant at least a partial dive into menus. There are some notable exceptions, such as the LFO shape, which is a mix of flipping a switch on the control panel and choosing options in the additional patch parameter menu. In most cases an additional patch parameter either has completely separate function form what is available on the control panel (such as the vibrato, which is fully controlled by menu parameters) or it had the function to modify the panel control behavior (such as envelope ranges, etc.). 

A useful work flow of the upgraded Prophet-600 for creating or editing patches could be as follows:

\begin{enumerate}
  \item Pre-production: set basic overall patch parameters, such as envelope shapes and routing, LFO targets and shape
  \item Production: use the panel controls to interactively design the sound 
  \item Post-production: add additional features, such as vibrato, bend modulation, spread, etc. for a final touch
\end{enumerate} 

Ideally, menu diving should be largely restricted to steps 1 and 3 so that uninterrupted hands-on and interactive work with the synthesizer is possible in step 2. 

\pagebreak
\chapter{Functionality}\label{function}

\section{Operating modes: preset and live mode}\label{uimode}

\input{uimode.tex}

\section{Loading and storing patches}\label{loadstorepatches}

\input{loadstorepatches}

\section{Oscillators and mix}\label{osc}

\input{osc.tex}

\pagebreak

\section{Volume and master tune}

To the right of the panel there are two global controls, \mastertune and \mastervol. The master tuning has a range of approximately $\pm 1$ semitone. Its purpose is to be able to tune the synth to other instruments without touching the internal, relative frequencies of the oscillators and thereby potentially changing the patch.

\mastervol and \mastertune are neither patch parameters nor settings. The two values are applied as set on the panel. The only exception is external MIDI control of volume (see section \ref{midiimplementation}). When the master volume is set via MIDI CC that volume level continues to be applied until either a new value is set by MIDI or until the \mastervol control is touched/changed. 

After power-up the instrument volume is always set to the value position of the \mastervol control.

\section{Filter}\label{filter}

\input{filter.tex}

\section{Envelopes and routing}\label{envelopes}

\input{envelopes.tex}

\section{Polyphonic, unison and chord mode, voice assigner priority}\label{poly-unison-voice}

\input{poly-unison-voice.tex}

\section{LFO}\label{lfo}

\input{lfo.tex}

\section{Poly-mod and oscillator sync}\label{polymod}

\input{polymod.tex}

\pagebreak

\section{Arpeggiator / sequencer clock and MIDI support}\label{sync}

The Prophet-600 offers a polyphonic sequencer with two tracks and an arpeggiator with three distinct pattern types. The details of operation are explained in sections \ref{arp} (arpeggiator) and \ref{seq} (sequencer).

The sequencer and arpeggiator share the same clock, which can simultaneously run both sequencer tracks and one arpeggiator pattern. In order to be able to operate the sequencer and/or arpeggiator in sync with other instruments, the upgraded Prophet-600 provides three different clock source methods which are configured in the miscellaneous setting \clocksync.
\begin{itemize}
  \item \textit{internal}: the internal clock is used. The \clock is edited like a menu patch parameter associated with number 0
  \item \textit{MIDI}: the clock is synced to the MIDI clocked received on the MIDI receive channel as set in the  miscellaneous settings
  \item \textit{tape}: the clock is synced to a fraction of a pulse clock received via the Tape In input on the rear of the instrument. 
\end{itemize}  
When the clock source is set to external (either \textit{MIDI} or \textit{tape}) the \clock sets the clock divide. The values are: 192,168,144,128,96,72,48,36,24,18,12,9,6,4,3,2.

It is also possible to sync the LFO to the sequencer / arpeggiator clock (internal or external). The menu parameter \lfosync provides the options \textit{off} (no sync, free running LFO) or one of the following \textit{1,2,3,4,5,6,8}. The latter sets the number of clock beats after which the LFO in reset.

Note that you can also operate the sequencer and/or arpeggiator in unison mode with all features of that mode (see section \ref{poly-unison-voice}). However, the voices are not shared between the tracks and the arpeggiator. The priority is as follows: arpeggiator, sequencer track 2, sequencer track 1. If activated, the arpeggiator will use all voices in unison mode and when the sequencer tracks 1 and 2 have a note on the same beat, only track 2 will play. Unison mode should be activated before starting the sequencer or arpeggiator.

\pagebreak

\section{Arpeggiator}\label{arp}

\input{arp.tex}

\pagebreak

\section{Sequencer}\label{seq}

\input{seq.tex}

\section{Vibrato}\label{vib}

\input{vibrato.tex}

\section{Pitch bender}\label{pitchbend}

\input{pitchbend.tex}

\section{Modulation wheel and modulation delay}\label{modwheel}

\input{modwheel.tex}

\section{Glide}\label{glide}

The Prophet-600 offers a glide function in polyphonic and unison mode. Generally speaking, the glide time determines the how fast the pitch glides from the start note to the target (played) note. Glide is based on voice, i.e. once a note is assigned to a voice the glide start note will be the last note of that voice (rather than, for example, the last played note). 

The way you set the glide time depends on the current active panel layout. When the panel layout is set to \textit{GliGli} you must use the menu parameter \glide to set the glide time. When the panel layout is set to \textit{SCI}, the menu parameter \glide is suppressed and the glide time is set by the \glidepot dial instead. 

For details on the panel layout options see section \ref{panelswitch}. 

Note that since glide is voice based, the voice assignment logic (as set using the parameter \assign, see \ref{poly-unison-voice}) has a strong impact on the behaviour of glide in polyphonic mode. The voice assignment logic determines the glide start note once a new note is played.

\section{Detune}\label{detune}

The upgraded Prophet-600 provides a method to detune the 6 voices against one another. This effect is used to make unison sounds broader and more lively. Detune is only applied when unison is activated. The menu parameter for setting detune is \detune. Note: the effect of the vintage spread (see section \ref{spreadsett}) is applied in all modes and is therefore added to detune in unison mode. 

The detune functions has been changed in version \version. Compared to versions 2.0 and 2.1 RC3 the detune is scaled with pitch is less pronounced for higher pitches. This change is designed such that the perceived detune is constant (or at least more constant) over the available pitch range. 

\section{Vintage / spread}\label{spreadsett}

\input{spread.tex}

\section{External CV in}\label{extcv}

The Prophet-600 offers the option to control the filter cut-off frequency using an external voltage source fed into the Prophet-600 via the \textbf{Filter CV In} plug on the rear panel. Applying a voltage to that input raises the filter cut-off frequency.

In the upgraded Prophet-600 the strength of the external CV input effect can be controlled using the menu parameter \extvolt. The parameter has been newly introduced in version \version. In versions 2.0 and 2.1 RC3 the external CV control strength is fixed and it is set to maximum by default. In the new version on the other hand the patch parameter value is zero and it therefore needs to be changed before using the external voltage control. 

One application of the external voltage control is that it is used in the popular "noise mod" of the Prophet-600 and in this mod the parameter controls the level of an additional noise source. 

\section{Velocity sensitivity}\label{velocity}

The Prophet-600 is equipped with a non-weighted keyboard without support for velocity. However, when played via MIDI, the upgraded Prophet-600 supports velocity sensitivity of amplitude and filter cut-off frequency. The respective velocity amounts are configured using the two menu parameters \ampvel and \filvel.

By default the \ampvel is set to half-way and the \filvel is set to zero. Amplitude and filter velocity are not supported in arpeggiator and sequencer.

\pagebreak

\chapter{Synthesizer setup and maintenance}\label{maintenance}

\section{Tuning}\label{tuning}

\input{tuning.tex}

\section{Switchable panel layout}\label{panelswitch}

\input{panelswitch.tex}

\section{MIDI integration}\label{midiintegration}

\input{midiintegration.tex}

\section{Voice deactivation}\label{voices}

The upgraded Prophet-600 provides a method for switching single voices off. This can be useful to suppress a voice that is damaged or for troubleshooting, e.g. isolating voices for testing. The "voice masking" is configured using the miscellaneous settings with \numberbut{4} and \numberbut{5} in \shiftmode or \shiftlock as follows
\begin{enumerate}
  \setlength\itemsep{0cm}
  \item Press \numberbut{4} to cycle through the 6 voice of the Prophet-600. This selection determines the functionality of the key \numberbut{5} in the setting menu.
  \item Press \numberbut{5} to toggle between on and off of the voice selected using \numberbut{4}. 
\end{enumerate}

Note: the voice masking is stored in the settings. It therefore applies to all patches and all modes and it is retained through a power cycle. If you are missing a voice you should check the voice masking.

\section{Transposition}\label{transposition}

In the upgraded Prophet-600 there are two types of transposition which you set in the same way. The first one is the transposition of the internal keyboard. The second is the on-the-fly transposition of the sequencer and arpeggiator. In \shiftmode or \shiftlock the last pressed key will define the transposition, the middle C3 being zero transposition. The transposition is also scrolled through the display for conformation. As stated above, adjusting the transposition affects both, playing from the internal keyboard and the sequencer and arpeggiator.

You can transpose the sequencer and arpeggiator on-the-fly by MIDI too (play a MIDI note while in \shiftmode or \shiftlock) but only in \textit{local off} mode. Otherwise MIDI notes are ignored. Note that while transposition (from internal keyboard or from external MIDI) transposes playing from the internal keyboard, the transposition will never affect how notes from external MIDI are played. This is for consistency reasons because MIDI notes sent by the Prophet-600 already include any transposition, both for normal playing and for sequencer and arpeggiator. When this data is recorded and played back to the Prophet-600 the transposition must not be applied (again) to the incoming MIDI notes. The keyboard transposition should be thought of as a configuration of the internal keyboard rather than a transposition of the patch. If you need transposition from an external MIDI keyboard you have to rely on the functionalities of your MIDI keyboard. 

\section{VCF limit}\label{limitsett}

In the upgraded Prophet-600 it is possible to limit the cut-off frequency of the filter to 22kHz in order to avoid strange filter behaviour in the ultrasonic range. The limit is switch on using \numberbut{9} in \shiftmode or \shiftlock. 

\section{Managing sound libraries via SysEx}\label{patchmgmt}

\input{patchmgmt.tex}

\section{Scaling adjustment}\label{scalingadj}

\input{maintenancemode.tex}

\section{Firmware upgrade}\label{fwupgrade}

\input{firmware.tex}  

\section{Instabilities of exponential FM}\label{fm}

The Prophet-600 has a hardware design flaw which leads to a bleed of the DC component of the oscillator B output to the pitch of oscillator A when \polymodosc with destination \polymodfreq is active. This section describes the consequences of this design, methods to assess the impact in your unit (such as detuning effects) and also some measures to compensate for and/or avoid detuning.

While the CEM3340 oscillator chip has a dedicated support for linear frequency modulation, Sequential Circuits chose no to use that option but instead designed the circuitry such that the output of oscillator B is fed directly into the control voltage of oscillator A. The control voltage input of oscillator A (i.e. the input that determines the frequency) is the sum of the note related voltage (i.e. the note which the oscillator is supposed to play) and the output of oscillator B. The amount of oscillator B contribution is set by \polymodosc. This design produces exponential FM since the frequency doubles with each 1V of control voltage input. Exponential FM (as opposed to linear FM) is common in polyphonic synthesizers and you find the same basic mechanism in the Prophet-5, for example. Exponential FM has the disadvantage that the poly-mod amount changes the pitch. Since we are dealing with non-calibrated, CV controlled components, medium to strong poly-mod patches may not be immediately transferable from one unit to another. However, experience shows that on most instruments the overall differences can be compensated by adjusting \oscfreq (better A than B), \freqfine and/or \polymodosc for a given poly-mod patch.

There is another problem with the Prophet-600 design, however. The DC component of oscillator B output is not suppressed before the signal is fed into oscillator A. For using the linear FM input, the CEM3340 specification recommends using a capacitor to remove any direct current. No such mechanism is in place in the Prophet-600 exponential FM. As a result, any DC voltage component from oscillator B directly changes the basic frequency of oscillator A. While you may accept the general effect that \polymodosc changes the pitch, the presence of the DC voltage has the distinctive disadvantage that chip specific (and therefore voice specific) variations affect the pitch. In the worst case, poly-mod completely detunes the Prophet-600 and makes chord playing impossible. Patches that sound clear and rich on one instrument may sound detuned and outright bad one another. 

There are three main sources for poly-mod induced voice-to-voice variations in pitch. First, away from the pulse width mid-position, pulse waveforms have a DC component and therefore oscillator B pulse width creates a shift in oscillator A frequency. The pulse width response is chip specific (with variations within production specifications). For the timbre of the sound such variations do not matter much (unless you are toying with the break-up points on either side) but in poly-mod it means that each voice can produce a slightly different pitch in oscillator A, depending on the pulse width variation of oscillator B. Second, the waveform output can have a general, chip specific DC voltage offset. This affects also the sawtooth waveform. Third: scaling differences in the oscillator A chips. The chip specific relation of voltage to frequency is compensated for by the built-in tuning mechanism. The FM voltage input in poly-mod is \underline{not} corrected for scaling differences. As a result, the DC components from the voices lead to different voltage shifts depending on the scaling characteristics of the oscillator A chips that are targeted by poly-mod, even in the absence of other variations in the DC components. 

The bottom line is that instrument specific voice-to-voice variations in poly-mod response can make strong poly-mod difficult, especially for chord playing. Maybe your instrument has only little variation and is well calibrated. If not, you can try the following measures to reduce the detuning effect of poly-mod. 

\begin{itemize}
  \item \textit{Differences in pulse width}: If your find that pulse width produces a strong voice-to-voice variation in your instrument, you should avoid using the pulse waveform on oscillator B for medium to strong poly-mod patches.      
  \item \textit{Differences in scaling}: You should not not only rely on tuning but should also perform regular scaling adjustments (see \ref{scalingadj}).
  \item \textit{Sawtooth waveform}: There can be inherent, chip specific differences in the DC offset of output waveforms. Empirically, this seems to be more likely/pronounced in the sawtooth and pulse wave forms. If voice-to-voice variations persist, you may try to also avoid sawtooth waveforms on oscillator B for medium to strong poly-mod patches.
  \item \textit{Chips and circuitry}: In case everything else fails, you may want to consider replacing selected CEM3340 chips. One tested Prophet-600 hardware modification involves inserting a capacitor into the poly-mod circuitry (following the Curtis recommendations for linear FM input, a similarly sized capacitor can be inserted at resistor R430 and so on, see \cite{p600siservicemanual}) in order to the remove the DC offset of oscillator B. This change is reported to make the instrument much more consistent but it also alters the characteristics significantly.
\end{itemize}

Practical suggestion for assessing the voice-to-voice differences in poly-mod response: Create a strong poly-mod patch and calibrate it to be harmonic (i.e. no beating sounds) using one note (voice). Make sure to choose a high sustain and short release. You can then start from key C and play and hold 6 notes up the scale. Each note is assigned to a different voice. When you release all but one note you will hear only that one voice. Check if there is a beating sound. You can either assess the level of detuning by listening or "measure" it by adjusting the frequency of oscillator A to remove the beating. If you choose the \assign option \textit{first} (see section \ref{poly-unison-voice}) and use zero release (filter and amplitude), the relation of note to voice will be completely reproducible. Activating and deactivating voices one-by-one (see \ref{voices}) is also possible (but more cumbersome).

A future version of the upgraded firmware may contain a calibration and correction mechanism in order to compensate for chip specific differences in poly-mod response.  

\end{flowtext}

\pagebreak
\chapter{Reference}

\begin{flowtext}

\section{Patch parameter overview}\label{patchref}

\input{patchref.tex}

\pagebreak
\section{Default patch}\label{defaultpatch}

\input{defaultpatch.tex}

\pagebreak
\section{Settings parameter overview}\label{settingsref}

\input{settingsref}

\end{flowtext}

\pagebreak

\section{Operation modes}\label{modes}

\begin{samepage}

\textbf{Live mode}

\nopagebreak

\scalebox{0.4}{
  \begin{tikzpicture}[scale=0.8]
  \node[font=\fontsize{26}{22}\selectfont, align=right, outer sep=0.5mm, anchor = west, text width=8cm] at (0cm,12cm) {Live mode:};
    \upperbuttons{13cm,7cm}{}{}

    \node[font=\fontsize{18}{22}\selectfont, align=left, outer sep=0.0mm, anchor = west, text width=8cm] at (29cm,5.25cm) {Panel controls};
    \node[font=\fontsize{18}{22}\selectfont, align=left, outer sep=0.0mm, anchor = west, text width=22cm] at (36cm,5.25cm) {(normal function)};
    \draw[line width=1pt]++(29cm,6cm)--++(30cm,0cm);     
    \node[font=\fontsize{18}{22}\selectfont, align=left, outer sep=0.0mm, anchor = west, text width=8cm] at (29cm,6.75cm) {Performance};
    \node[font=\fontsize{18}{22}\selectfont, align=left, outer sep=0.0mm, anchor = west, text width=22cm] at (36cm,6.75cm) {(normal function)};
    \draw[line width=1pt]++(29cm,7.5cm)--++(30cm,0cm);     
    \node[font=\fontsize{18}{22}\selectfont, align=left, outer sep=0.0mm, anchor = west, text width=8cm] at (29cm,8.25cm) {Keyboard};
    \node[font=\fontsize{18}{22}\selectfont, align=left, outer sep=0.0mm, anchor = west, text width=22cm] at (36cm,8.25cm) {(normal function)};
    \draw[line width=1pt]++(29cm,9cm)--++(30cm,0cm);     
    \node[font=\fontsize{18}{22}\selectfont, align=left, outer sep=0.0mm, anchor = west, text width=8cm] at (29cm,9.75cm) {Display};
    \node[font=\fontsize{18}{22}\selectfont, align=left, outer sep=0.0mm, anchor = west, text width=22cm] at (36cm,9.75cm) {Show parameter values};
    \draw[line width=1pt]++(29cm,10.5cm)--++(30cm,0cm);     
    \node[font=\fontsize{18}{22}\selectfont, align=left, outer sep=0.0mm, anchor = west, text width=8cm] at (29cm,11.25cm) {Number pad};
    \node[font=\fontsize{18}{22}\selectfont, align=left, outer sep=0.0mm, anchor = west, text width=22cm] at (36cm,11.25cm) {Select patch parameter};
    \draw[line width=1pt]++(29cm,12cm)--++(30cm,0cm);     
    \node[font=\fontsize{18}{22}\selectfont, align=left, outer sep=0.0mm, anchor = west, text width=8cm] at (29cm,12.75cm) {Record};
    \node[font=\fontsize{18}{22}\selectfont, align=left, outer sep=0.0mm, anchor = west, text width=22cm] at (36cm,12.75cm) {Enter record mode};
    \draw[line width=1pt]++(29cm,13.5cm)--++(30cm,0cm);  
    \node[font=\fontsize{18}{22}\selectfont, align=left, outer sep=0.0mm, anchor = west, text width=8cm] at (29cm,14.25cm) {Preset};
    \node[font=\fontsize{18}{22}\selectfont, align=left, outer sep=0.0mm, anchor = west, text width=22cm] at (36cm,14.25cm) {Leave live mode and enter preset patch mode};
    \draw[line width=1pt]++(29cm,15cm)--++(30cm,0cm);  
    \node[font=\fontsize{18}{22}\selectfont, align=left, outer sep=0.0mm, anchor = west, text width=8cm] at (29cm,15.75cm) {Tune};
    \node[font=\fontsize{18}{22}\selectfont, align=left, outer sep=0.0mm, anchor = west, text width=22cm] at (36cm,15.75cm){Start tuning procedure};
    \draw[line width=1pt]++(29cm,16.5cm)--++(30cm,0cm);  
    \node[font=\fontsize{18}{22}\selectfont, align=left, outer sep=0.0mm, anchor = west, text width=8cm] at (29cm,17.25cm) {From Tape};
    \node[font=\fontsize{18}{22}\selectfont, align=left, outer sep=0.0mm, anchor = west, text width=22cm] at (36cm,17.25cm) {Shift and shift-lock modes (double press)};
    \draw[line width=1pt]++(29cm,18cm)--++(30cm,0cm);  
    \node[font=\fontsize{18}{22}\selectfont, align=left, outer sep=0.0mm, anchor = west, text width=8cm] at (29cm,18.75cm) {To Tape};
    \node[font=\fontsize{18}{22}\selectfont, align=left, outer sep=0.0mm, anchor = west, text width=22cm] at (36cm,18.75cm) {};
    
    \draw[line width=1pt]++(35cm,4.5cm)--++(0cm,15cm);  

  \end{tikzpicture}
}

\end{samepage}

\begin{samepage}

\textbf{Preset panel mode}

\nopagebreak

\scalebox{0.4}{
  \begin{tikzpicture}[scale=0.8]
  \node[font=\fontsize{26}{22}\selectfont, align=right, outer sep=0.5mm, anchor = west, text width=8cm] at (0cm,12cm) {Preset panel mode:};
    \upperbuttons{13cm,7cm}{PT}{}

    \node[font=\fontsize{18}{22}\selectfont, align=left, outer sep=0.0mm, anchor = west, text width=8cm] at (29cm,5.25cm) {Panel controls};
    \node[font=\fontsize{18}{22}\selectfont, align=left, outer sep=0.0mm, anchor = west, text width=22cm] at (36cm,5.25cm) {Pick-me-up function};
    \draw[line width=1pt]++(29cm,6cm)--++(30cm,0cm);     
    \node[font=\fontsize{18}{22}\selectfont, align=left, outer sep=0.0mm, anchor = west, text width=8cm] at (29cm,6.75cm) {Performance};
    \node[font=\fontsize{18}{22}\selectfont, align=left, outer sep=0.0mm, anchor = west, text width=22cm] at (36cm,6.75cm) {(normal function)};
    \draw[line width=1pt]++(29cm,7.5cm)--++(30cm,0cm);     
    \node[font=\fontsize{18}{22}\selectfont, align=left, outer sep=0.0mm, anchor = west, text width=8cm] at (29cm,8.25cm) {Keyboard};
    \node[font=\fontsize{18}{22}\selectfont, align=left, outer sep=0.0mm, anchor = west, text width=22cm] at (36cm,8.25cm) {(normal function)};
    \draw[line width=1pt]++(29cm,9cm)--++(30cm,0cm);     
    \node[font=\fontsize{18}{22}\selectfont, align=left, outer sep=0.0mm, anchor = west, text width=8cm] at (29cm,9.75cm) {Display};
    \node[font=\fontsize{18}{22}\selectfont, align=left, outer sep=0.0mm, anchor = west, text width=22cm] at (36cm,9.75cm) {Pick-me-up display (value or relative position)};
    \draw[line width=1pt]++(29cm,10.5cm)--++(30cm,0cm);     
    \node[font=\fontsize{18}{22}\selectfont, align=left, outer sep=0.0mm, anchor = west, text width=8cm] at (29cm,11.25cm) {Number pad};
    \node[font=\fontsize{18}{22}\selectfont, align=left, outer sep=0.0mm, anchor = west, text width=22cm] at (36cm,11.25cm) {Select patch parameter};
    \draw[line width=1pt]++(29cm,12cm)--++(30cm,0cm);     
    \node[font=\fontsize{18}{22}\selectfont, align=left, outer sep=0.0mm, anchor = west, text width=8cm] at (29cm,12.75cm) {Record};
    \node[font=\fontsize{18}{22}\selectfont, align=left, outer sep=0.0mm, anchor = west, text width=22cm] at (36cm,12.75cm) {Enter record mode};
    \draw[line width=1pt]++(29cm,13.5cm)--++(30cm,0cm);  
    \node[font=\fontsize{18}{22}\selectfont, align=left, outer sep=0.0mm, anchor = west, text width=8cm] at (29cm,14.25cm) {Preset};
    \node[font=\fontsize{18}{22}\selectfont, align=left, outer sep=0.0mm, anchor = west, text width=22cm] at (36cm,14.25cm) {Leave preset mode and enter live mode};
    \draw[line width=1pt]++(29cm,15cm)--++(30cm,0cm);  
    \node[font=\fontsize{18}{22}\selectfont, align=left, outer sep=0.0mm, anchor = west, text width=8cm] at (29cm,15.75cm) {Tune};
    \node[font=\fontsize{18}{22}\selectfont, align=left, outer sep=0.0mm, anchor = west, text width=22cm] at (36cm,15.75cm) {Start tuning procedure};
    \draw[line width=1pt]++(29cm,16.5cm)--++(30cm,0cm);  
    \node[font=\fontsize{18}{22}\selectfont, align=left, outer sep=0.0mm, anchor = west, text width=8cm] at (29cm,17.25cm) {From Tape};
    \node[font=\fontsize{18}{22}\selectfont, align=left, outer sep=0.0mm, anchor = west, text width=22cm] at (36cm,17.25cm) {Shift and shift-lock modes (double press)};
    \draw[line width=1pt]++(29cm,18cm)--++(30cm,0cm);  
    \node[font=\fontsize{18}{22}\selectfont, align=left, outer sep=0.0mm, anchor = west, text width=8cm] at (29cm,18.75cm) {To Tape};
    \node[font=\fontsize{18}{22}\selectfont, align=left, outer sep=0.0mm, anchor = west, text width=22cm] at (36cm,18.75cm) {Enter preset patch mode};
    
    \draw[line width=1pt]++(35cm,4.5cm)--++(0cm,15cm);  

  \end{tikzpicture}
}

\end{samepage}

\begin{samepage}

\textbf{Preset patch mode}

\nopagebreak

\scalebox{0.4}{
  \begin{tikzpicture}[scale=0.8]
  \node[font=\fontsize{26}{22}\selectfont, align=right, outer sep=0.5mm, anchor = west, text width=8cm] at (0cm,12cm) {Preset patch mode:};
    \upperbuttons{13cm,7cm}{P}{}

    \node[font=\fontsize{18}{22}\selectfont, align=left, outer sep=0.0mm, anchor = west, text width=8cm] at (29cm,5.25cm) {Panel controls};
    \node[font=\fontsize{18}{22}\selectfont, align=left, outer sep=0.0mm, anchor = west, text width=22cm] at (36cm,5.25cm) {(normal function)};
    \draw[line width=1pt]++(29cm,6cm)--++(30cm,0cm);     
    \node[font=\fontsize{18}{22}\selectfont, align=left, outer sep=0.0mm, anchor = west, text width=8cm] at (29cm,6.75cm) {Performance};
    \node[font=\fontsize{18}{22}\selectfont, align=left, outer sep=0.0mm, anchor = west, text width=22cm] at (36cm,6.75cm) {(normal function)};
    \draw[line width=1pt]++(29cm,7.5cm)--++(30cm,0cm);     
    \node[font=\fontsize{18}{22}\selectfont, align=left, outer sep=0.0mm, anchor = west, text width=8cm] at (29cm,8.25cm) {Keyboard};
    \node[font=\fontsize{18}{22}\selectfont, align=left, outer sep=0.0mm, anchor = west, text width=22cm] at (36cm,8.25cm) {(normal function)};
    \draw[line width=1pt]++(29cm,9cm)--++(30cm,0cm);     
    \node[font=\fontsize{18}{22}\selectfont, align=left, outer sep=0.0mm, anchor = west, text width=8cm] at (29cm,9.75cm) {Display};
    \node[font=\fontsize{18}{22}\selectfont, align=left, outer sep=0.0mm, anchor = west, text width=22cm] at (36cm,9.75cm) {Display patch number};
    \draw[line width=1pt]++(29cm,10.5cm)--++(30cm,0cm);     
    \node[font=\fontsize{18}{22}\selectfont, align=left, outer sep=0.0mm, anchor = west, text width=8cm] at (29cm,11.25cm) {Number pad};
    \node[font=\fontsize{18}{22}\selectfont, align=left, outer sep=0.0mm, anchor = west, text width=22cm] at (36cm,11.25cm) {Enter patch number};
    \draw[line width=1pt]++(29cm,12cm)--++(30cm,0cm);     
    \node[font=\fontsize{18}{22}\selectfont, align=left, outer sep=0.0mm, anchor = west, text width=8cm] at (29cm,12.75cm) {Record};
    \node[font=\fontsize{18}{22}\selectfont, align=left, outer sep=0.0mm, anchor = west, text width=22cm] at (36cm,12.75cm) {Enter record mode};
    \draw[line width=1pt]++(29cm,13.5cm)--++(30cm,0cm);  
    \node[font=\fontsize{18}{22}\selectfont, align=left, outer sep=0.0mm, anchor = west, text width=8cm] at (29cm,14.25cm) {Preset};
    \node[font=\fontsize{18}{22}\selectfont, align=left, outer sep=0.0mm, anchor = west, text width=22cm] at (36cm,14.25cm) {Leave preset mode and enter live mode};
    \draw[line width=1pt]++(29cm,15cm)--++(30cm,0cm);  
    \node[font=\fontsize{18}{22}\selectfont, align=left, outer sep=0.0mm, anchor = west, text width=8cm] at (29cm,15.75cm) {Tune};
    \node[font=\fontsize{18}{22}\selectfont, align=left, outer sep=0.0mm, anchor = west, text width=22cm] at (36cm,15.75cm) {Start tuning procedure};
    \draw[line width=1pt]++(29cm,16.5cm)--++(30cm,0cm);  
    \node[font=\fontsize{18}{22}\selectfont, align=left, outer sep=0.0mm, anchor = west, text width=8cm] at (29cm,17.25cm) {From Tape};
    \node[font=\fontsize{18}{22}\selectfont, align=left, outer sep=0.0mm, anchor = west, text width=22cm] at (36cm,17.25cm) {Shift and shift-lock modes (double press)};
    \draw[line width=1pt]++(29cm,18cm)--++(30cm,0cm);  
    \node[font=\fontsize{18}{22}\selectfont, align=left, outer sep=0.0mm, anchor = west, text width=8cm] at (29cm,18.75cm) {To Tape};
    \node[font=\fontsize{18}{22}\selectfont, align=left, outer sep=0.0mm, anchor = west, text width=22cm] at (36cm,18.75cm) {Enter preset panel mode};
    
    \draw[line width=1pt]++(35cm,4.5cm)--++(0cm,15cm);  

  \end{tikzpicture}
}

\end{samepage}

\begin{samepage}

\textbf{Record mode}

\nopagebreak

\scalebox{0.4}{
  \begin{tikzpicture}[scale=0.8]
  \node[font=\fontsize{26}{22}\selectfont, align=right, outer sep=0.5mm, anchor = west, text width=8cm] at (0cm,12cm) {Record mode:};
    \upperbuttons{13cm,7cm}{R}{R}

    \node[font=\fontsize{18}{22}\selectfont, align=left, outer sep=0.0mm, anchor = west, text width=8cm] at (29cm,5.25cm) {Panel controls};
    \node[font=\fontsize{18}{22}\selectfont, align=left, outer sep=0.0mm, anchor = west, text width=22cm] at (36cm,5.25cm) {(normal function)};
    \draw[line width=1pt]++(29cm,6cm)--++(30cm,0cm);     
    \node[font=\fontsize{18}{22}\selectfont, align=left, outer sep=0.0mm, anchor = west, text width=8cm] at (29cm,6.75cm) {Performance};
    \node[font=\fontsize{18}{22}\selectfont, align=left, outer sep=0.0mm, anchor = west, text width=22cm] at (36cm,6.75cm) {(normal function)};
    \draw[line width=1pt]++(29cm,7.5cm)--++(30cm,0cm);     
    \node[font=\fontsize{18}{22}\selectfont, align=left, outer sep=0.0mm, anchor = west, text width=8cm] at (29cm,8.25cm) {Keyboard};
    \node[font=\fontsize{18}{22}\selectfont, align=left, outer sep=0.0mm, anchor = west, text width=22cm] at (36cm,8.25cm) {(normal function)};
    \draw[line width=1pt]++(29cm,9cm)--++(30cm,0cm);     
    \node[font=\fontsize{18}{22}\selectfont, align=left, outer sep=0.0mm, anchor = west, text width=8cm] at (29cm,9.75cm) {Display};
    \node[font=\fontsize{18}{22}\selectfont, align=left, outer sep=0.0mm, anchor = west, text width=22cm] at (36cm,9.75cm) {Display patch number};
    \draw[line width=1pt]++(29cm,10.5cm)--++(30cm,0cm);     
    \node[font=\fontsize{18}{22}\selectfont, align=left, outer sep=0.0mm, anchor = west, text width=8cm] at (29cm,11.25cm) {Number pad};
    \node[font=\fontsize{18}{22}\selectfont, align=left, outer sep=0.0mm, anchor = west, text width=22cm] at (36cm,11.25cm) {Enter patch number};
    \draw[line width=1pt]++(29cm,12cm)--++(30cm,0cm);     
    \node[font=\fontsize{18}{22}\selectfont, align=left, outer sep=0.0mm, anchor = west, text width=8cm] at (29cm,12.75cm) {Record};
    \node[font=\fontsize{18}{22}\selectfont, align=left, outer sep=0.0mm, anchor = west, text width=22cm] at (36cm,12.75cm) {Leave record mode};
    \draw[line width=1pt]++(29cm,13.5cm)--++(30cm,0cm);  
    \node[font=\fontsize{18}{22}\selectfont, align=left, outer sep=0.0mm, anchor = west, text width=8cm] at (29cm,14.25cm) {Preset};
    \node[font=\fontsize{18}{22}\selectfont, align=left, outer sep=0.0mm, anchor = west, text width=22cm] at (36cm,14.25cm) {Leave record mode};
    \draw[line width=1pt]++(29cm,15cm)--++(30cm,0cm);  
    \node[font=\fontsize{18}{22}\selectfont, align=left, outer sep=0.0mm, anchor = west, text width=8cm] at (29cm,15.75cm) {Tune};
    \node[font=\fontsize{18}{22}\selectfont, align=left, outer sep=0.0mm, anchor = west, text width=22cm] at (36cm,15.75cm) {(normal function)};
    \draw[line width=1pt]++(29cm,16.5cm)--++(30cm,0cm);  
    \node[font=\fontsize{18}{22}\selectfont, align=left, outer sep=0.0mm, anchor = west, text width=8cm] at (29cm,17.25cm) {From Tape};
    \node[font=\fontsize{18}{22}\selectfont, align=left, outer sep=0.0mm, anchor = west, text width=22cm] at (36cm,17.25cm) {(normal function)};
    \draw[line width=1pt]++(29cm,18cm)--++(30cm,0cm);  
    \node[font=\fontsize{18}{22}\selectfont, align=left, outer sep=0.0mm, anchor = west, text width=8cm] at (29cm,18.75cm) {To Tape};
    \node[font=\fontsize{18}{22}\selectfont, align=left, outer sep=0.0mm, anchor = west, text width=22cm] at (36cm,18.75cm) {};
    
    \draw[line width=1pt]++(35cm,4.5cm)--++(0cm,15cm);  

  \end{tikzpicture}
}

\end{samepage}

\begin{samepage}

\textbf{Shift-lock mode}

\nopagebreak

\scalebox{0.4}{
  \begin{tikzpicture}[scale=0.8]
  \node[font=\fontsize{26}{22}\selectfont, align=right, outer sep=0.5mm, anchor = west, text width=8cm] at (0cm,12cm) {Shift-lock mode:};
    \upperbuttons{13cm,7cm}{F}{F}

    \node[font=\fontsize{18}{22}\selectfont, align=left, outer sep=0.0mm, anchor = west, text width=8cm] at (29cm,5.25cm) {Panel controls};
    \node[font=\fontsize{18}{22}\selectfont, align=left, outer sep=0.0mm, anchor = west, text width=22cm] at (36cm,5.25cm) {(normal function)};
    \draw[line width=1pt]++(29cm,6cm)--++(30cm,0cm);     
    \node[font=\fontsize{18}{22}\selectfont, align=left, outer sep=0.0mm, anchor = west, text width=8cm] at (29cm,6.75cm) {Performance};
    \node[font=\fontsize{18}{22}\selectfont, align=left, outer sep=0.0mm, anchor = west, text width=22cm] at (36cm,6.75cm) {(normal function)};
    \draw[line width=1pt]++(29cm,7.5cm)--++(30cm,0cm);     
    \node[font=\fontsize{18}{22}\selectfont, align=left, outer sep=0.0mm, anchor = west, text width=8cm] at (29cm,8.25cm) {Keyboard};
    \node[font=\fontsize{18}{22}\selectfont, align=left, outer sep=0.0mm, anchor = west, text width=22cm] at (36cm,8.25cm) {Transposition};
    \draw[line width=1pt]++(29cm,9cm)--++(30cm,0cm);     
    \node[font=\fontsize{18}{22}\selectfont, align=left, outer sep=0.0mm, anchor = west, text width=8cm] at (29cm,9.75cm) {Display};
    \node[font=\fontsize{18}{22}\selectfont, align=left, outer sep=0.0mm, anchor = west, text width=22cm] at (36cm,9.75cm) {Display of miscellaneous settings and messages};
    \draw[line width=1pt]++(29cm,10.5cm)--++(30cm,0cm);     
    \node[font=\fontsize{18}{22}\selectfont, align=left, outer sep=0.0mm, anchor = west, text width=8cm] at (29cm,11.25cm) {Number pad};
    \node[font=\fontsize{18}{22}\selectfont, align=left, outer sep=0.0mm, anchor = west, text width=22cm] at (36cm,11.25cm) {Miscellaneous settings};
    \draw[line width=1pt]++(29cm,12cm)--++(30cm,0cm);     
    \node[font=\fontsize{18}{22}\selectfont, align=left, outer sep=0.0mm, anchor = west, text width=8cm] at (29cm,12.75cm) {Record};
    \node[font=\fontsize{18}{22}\selectfont, align=left, outer sep=0.0mm, anchor = west, text width=22cm] at (36cm,12.75cm) {Enter patch management mode};
    \draw[line width=1pt]++(29cm,13.5cm)--++(30cm,0cm);  
    \node[font=\fontsize{18}{22}\selectfont, align=left, outer sep=0.0mm, anchor = west, text width=8cm] at (29cm,14.25cm) {Preset};
    \node[font=\fontsize{18}{22}\selectfont, align=left, outer sep=0.0mm, anchor = west, text width=22cm] at (36cm,14.25cm) {Load default patch (requires confirmation)};
    \draw[line width=1pt]++(29cm,15cm)--++(30cm,0cm);  
    \node[font=\fontsize{18}{22}\selectfont, align=left, outer sep=0.0mm, anchor = west, text width=8cm] at (29cm,15.75cm) {Tune};
    \node[font=\fontsize{18}{22}\selectfont, align=left, outer sep=0.0mm, anchor = west, text width=22cm] at (36cm,15.75cm) {Enter per note tuning mode};
    \draw[line width=1pt]++(29cm,16.5cm)--++(30cm,0cm);  
    \node[font=\fontsize{18}{22}\selectfont, align=left, outer sep=0.0mm, anchor = west, text width=8cm] at (29cm,17.25cm) {From Tape};
    \node[font=\fontsize{18}{22}\selectfont, align=left, outer sep=0.0mm, anchor = west, text width=22cm] at (36cm,17.25cm) {Leave shifted mode};
    \draw[line width=1pt]++(29cm,18cm)--++(30cm,0cm);  
    \node[font=\fontsize{18}{22}\selectfont, align=left, outer sep=0.0mm, anchor = west, text width=8cm] at (29cm,18.75cm) {To Tape};
    \node[font=\fontsize{18}{22}\selectfont, align=left, outer sep=0.0mm, anchor = west, text width=22cm] at (36cm,18.75cm) {};
    
    \draw[line width=1pt]++(35cm,4.5cm)--++(0cm,15cm);  

  \end{tikzpicture}
}

\end{samepage}

\begin{samepage}

\textbf{Sequencer editing mode}

\nopagebreak

\scalebox{0.4}{
  \begin{tikzpicture}[scale=0.8]
  \node[font=\fontsize{26}{22}\selectfont, align=right, outer sep=0.5mm, anchor = west, text width=8cm] at (0cm,12cm) {Sequencer editing mode:};
    \upperbuttons{13cm,7cm}{R}{}

    \node[font=\fontsize{18}{22}\selectfont, align=left, outer sep=0.0mm, anchor = west, text width=8cm] at (29cm,5.25cm) {Panel controls};
    \node[font=\fontsize{18}{22}\selectfont, align=left, outer sep=0.0mm, anchor = west, text width=22cm] at (36cm,5.25cm) {(normal function)};
    \draw[line width=1pt]++(29cm,6cm)--++(30cm,0cm);     
    \node[font=\fontsize{18}{22}\selectfont, align=left, outer sep=0.0mm, anchor = west, text width=8cm] at (29cm,6.75cm) {Performance};
    \node[font=\fontsize{18}{22}\selectfont, align=left, outer sep=0.0mm, anchor = west, text width=22cm] at (36cm,6.75cm) {(normal function)};
    \draw[line width=1pt]++(29cm,7.5cm)--++(30cm,0cm);     
    \node[font=\fontsize{18}{22}\selectfont, align=left, outer sep=0.0mm, anchor = west, text width=8cm] at (29cm,8.25cm) {Keyboard};
    \node[font=\fontsize{18}{22}\selectfont, align=left, outer sep=0.0mm, anchor = west, text width=22cm] at (36cm,8.25cm) {Enter steps in the sequence};
    \draw[line width=1pt]++(29cm,9cm)--++(30cm,0cm);     
    \node[font=\fontsize{18}{22}\selectfont, align=left, outer sep=0.0mm, anchor = west, text width=8cm] at (29cm,9.75cm) {Display};
    \node[font=\fontsize{18}{22}\selectfont, align=left, outer sep=0.0mm, anchor = west, text width=22cm] at (36cm,9.75cm) {Display the number of steps};
    \draw[line width=1pt]++(29cm,10.5cm)--++(30cm,0cm);     
    \node[font=\fontsize{18}{22}\selectfont, align=left, outer sep=0.0mm, anchor = west, text width=8cm] at (29cm,11.25cm) {Number pad};
    \node[font=\fontsize{18}{22}\selectfont, align=left, outer sep=0.0mm, anchor = west, text width=22cm] at (36cm,11.25cm) {Special functions of buttons 0, 1 and 2};
    \draw[line width=1pt]++(29cm,12cm)--++(30cm,0cm);     
    \node[font=\fontsize{18}{22}\selectfont, align=left, outer sep=0.0mm, anchor = west, text width=8cm] at (29cm,12.75cm) {Record};
    \node[font=\fontsize{18}{22}\selectfont, align=left, outer sep=0.0mm, anchor = west, text width=22cm] at (36cm,12.75cm) {Leave editing mode};
    \draw[line width=1pt]++(29cm,13.5cm)--++(30cm,0cm);  
    \node[font=\fontsize{18}{22}\selectfont, align=left, outer sep=0.0mm, anchor = west, text width=8cm] at (29cm,14.25cm) {Preset};
    \node[font=\fontsize{18}{22}\selectfont, align=left, outer sep=0.0mm, anchor = west, text width=22cm] at (36cm,14.25cm) {};
    \draw[line width=1pt]++(29cm,15cm)--++(30cm,0cm);  
    \node[font=\fontsize{18}{22}\selectfont, align=left, outer sep=0.0mm, anchor = west, text width=8cm] at (29cm,15.75cm) {Tune};
    \node[font=\fontsize{18}{22}\selectfont, align=left, outer sep=0.0mm, anchor = west, text width=22cm] at (36cm,15.75cm) {(normal function)};
    \draw[line width=1pt]++(29cm,16.5cm)--++(30cm,0cm);  
    \node[font=\fontsize{18}{22}\selectfont, align=left, outer sep=0.0mm, anchor = west, text width=8cm] at (29cm,17.25cm) {From Tape};
    \node[font=\fontsize{18}{22}\selectfont, align=left, outer sep=0.0mm, anchor = west, text width=22cm] at (36cm,17.25cm) {(normal function)};
    \draw[line width=1pt]++(29cm,18cm)--++(30cm,0cm);  
    \node[font=\fontsize{18}{22}\selectfont, align=left, outer sep=0.0mm, anchor = west, text width=8cm] at (29cm,18.75cm) {To Tape};
    \node[font=\fontsize{18}{22}\selectfont, align=left, outer sep=0.0mm, anchor = west, text width=22cm] at (36cm,18.75cm) {Hold to access patch parameters via number pad};
    
    \draw[line width=1pt]++(35cm,4.5cm)--++(0cm,15cm);  

  \end{tikzpicture}
}

\end{samepage}

\begin{samepage}

\textbf{Patch management mode}

\nopagebreak

\scalebox{0.4}{
  \begin{tikzpicture}[scale=0.8]
  \node[font=\fontsize{26}{22}\selectfont, align=right, outer sep=0.5mm, anchor = west, text width=8cm] at (0cm,12cm) {Patch management mode:};
    \upperbuttons{13cm,7cm}{P}{P}

    \node[font=\fontsize{18}{22}\selectfont, align=left, outer sep=0.0mm, anchor = west, text width=8cm] at (29cm,5.25cm) {Panel controls};
    \node[font=\fontsize{18}{22}\selectfont, align=left, outer sep=0.0mm, anchor = west, text width=22cm] at (36cm,5.25cm) {(normal function)};
    \draw[line width=1pt]++(29cm,6cm)--++(30cm,0cm);     
    \node[font=\fontsize{18}{22}\selectfont, align=left, outer sep=0.0mm, anchor = west, text width=8cm] at (29cm,6.75cm) {Performance};
    \node[font=\fontsize{18}{22}\selectfont, align=left, outer sep=0.0mm, anchor = west, text width=22cm] at (36cm,6.75cm) {(normal function)};
    \draw[line width=1pt]++(29cm,7.5cm)--++(30cm,0cm);     
    \node[font=\fontsize{18}{22}\selectfont, align=left, outer sep=0.0mm, anchor = west, text width=8cm] at (29cm,8.25cm) {Keyboard};
    \node[font=\fontsize{18}{22}\selectfont, align=left, outer sep=0.0mm, anchor = west, text width=22cm] at (36cm,8.25cm) {(normal function)};
    \draw[line width=1pt]++(29cm,9cm)--++(30cm,0cm);     
    \node[font=\fontsize{18}{22}\selectfont, align=left, outer sep=0.0mm, anchor = west, text width=8cm] at (29cm,9.75cm) {Display};
    \node[font=\fontsize{18}{22}\selectfont, align=left, outer sep=0.0mm, anchor = west, text width=22cm] at (36cm,9.75cm) {Patch number input, confirmation text};
    \draw[line width=1pt]++(29cm,10.5cm)--++(30cm,0cm);     
    \node[font=\fontsize{18}{22}\selectfont, align=left, outer sep=0.0mm, anchor = west, text width=8cm] at (29cm,11.25cm) {Number pad};
    \node[font=\fontsize{18}{22}\selectfont, align=left, outer sep=0.0mm, anchor = west, text width=22cm] at (36cm,11.25cm) {Patch number entry};
    \draw[line width=1pt]++(29cm,12cm)--++(30cm,0cm);     
    \node[font=\fontsize{18}{22}\selectfont, align=left, outer sep=0.0mm, anchor = west, text width=8cm] at (29cm,12.75cm) {Record};
    \node[font=\fontsize{18}{22}\selectfont, align=left, outer sep=0.0mm, anchor = west, text width=22cm] at (36cm,12.75cm) {Leave patch management mode};
    \draw[line width=1pt]++(29cm,13.5cm)--++(30cm,0cm);  
    \node[font=\fontsize{18}{22}\selectfont, align=left, outer sep=0.0mm, anchor = west, text width=8cm] at (29cm,14.25cm) {Preset};
    \node[font=\fontsize{18}{22}\selectfont, align=left, outer sep=0.0mm, anchor = west, text width=22cm] at (36cm,14.25cm) {Dump entire patch bank};
    \draw[line width=1pt]++(29cm,15cm)--++(30cm,0cm);  
    \node[font=\fontsize{18}{22}\selectfont, align=left, outer sep=0.0mm, anchor = west, text width=8cm] at (29cm,15.75cm) {Tune};
    \node[font=\fontsize{18}{22}\selectfont, align=left, outer sep=0.0mm, anchor = west, text width=22cm] at (36cm,15.75cm) {(normal function)};
    \draw[line width=1pt]++(29cm,16.5cm)--++(30cm,0cm);  
    \node[font=\fontsize{18}{22}\selectfont, align=left, outer sep=0.0mm, anchor = west, text width=8cm] at (29cm,17.25cm) {From Tape};
    \node[font=\fontsize{18}{22}\selectfont, align=left, outer sep=0.0mm, anchor = west, text width=22cm] at (36cm,17.25cm) {(normal function)};
    \draw[line width=1pt]++(29cm,18cm)--++(30cm,0cm);  
    \node[font=\fontsize{18}{22}\selectfont, align=left, outer sep=0.0mm, anchor = west, text width=8cm] at (29cm,18.75cm) {To Tape};
    \node[font=\fontsize{18}{22}\selectfont, align=left, outer sep=0.0mm, anchor = west, text width=22cm] at (36cm,18.75cm) {};
    
    \draw[line width=1pt]++(35cm,4.5cm)--++(0cm,15cm);  

  \end{tikzpicture}
}

\end{samepage}

\pagebreak

\begin{flowtext}

\chapter{MIDI control implementation}\label{midiimplementation}

\input{midiimplementation.tex}

\end{flowtext}

\pagebreak

\begin{thebibliography}{50} 

\bibitem{newversion}Latest firmware project page (to follow)
\bibitem{gligli}GliGli blog and project pages, http://gliglisynth.blogspot.com/, http://gligli.github.io/p600fw/
\bibitem{imogen}Imogen Synth blog and project pages, https://prophet600revisited.blogspot.com/, https://github.com/image-et-son/p600fw
\bibitem{curtis}Curtis Electro Music on Webarchive, https://web.archive.org/web/20130502132536/http://curtiselectromusic.com/Customers\_and\_Instruments.html
\bibitem{modinstructions} Prophet-600 Modification Instructions, see GliGli project pages and links above
\bibitem{teensy}Teensy++ 2.0 manufacturer information: http://www.pjrc.com/teensy/index.html
\bibitem{p600siownersmanual}Prophet-600 Owner's Manual, Sequential Circuits
\bibitem{p600siservicemanual} Prophet-600 Service Manual, Sequential Circuits
\bibitem{synthgraphics} Synthgraphics (http://www.synthgraphics.com/). The provider of panel overlays for modded synthesizers created an overlay for the GliGli firmware panel layout of the Prophet-600.
\bibitem{teensyloader} Teensy code loader application from pjrc, https://www.pjrc.com/teensy/loader.html
\bibitem{p600spirit}Prophet-600 Spirit blog, http://prophet600.blogspot.com/

\end{thebibliography}

\end{document}

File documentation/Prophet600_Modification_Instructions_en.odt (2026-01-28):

GliGli’s Sequential Circuits Prophet 600 Firmware Upgrade

Modification Instructions

Document version: 1.0 (13.11.201)

Separated from original comprehensive documentation

Table of Contents

###### About this Document

This document captures all information regarding the GliGli firmware upgrade for the Sequential Circuits Prophet 600 synthesiser using a Teensy++ 2.0 USB Development Board as a drop-in replacement for the original Z80 microprocessor. This manual is for the 2.0 release.

Please understand that following these directions and completing these steps are presented at the user’s risk. The user assumes all responsibility for determining the suitability of this upgrade to their instrument and the safety of themselves and others.

Note on the documentation history: the User Manual (oringinally included here) has been moved to a separate document. The original instructions from GliGli in this document are unchanged. It is expected that the content of this document is independent from further software developments, unless the firmware is migrated to a different technical platform. The software information has been omitted from this document.

###### History of the Project

(GliGli) I love vintage analog synthesizers, and to be honest, my dream synth would be a Prophet 5, but when I heard what the Prophet 600 was capable of tone wise, I immediately thought its major weaknesses -- the lousy computer part, software envelopes and LFO -- could become its strength with a remake; basically the whole internal synth in voltage-controlled from a nice 14bit DAC, so with a fast modern microcontroller, it could become awesome, maybe even better than a Prophet 5!

I'm a long time coder, I love embedded/bare metal stuff, electronics. Synth wise, I’ve already worked on 2 projects:

1. An Atmel based two DCOs + SSM2044 monosynth:
  https (https://github.com/gligli/anaglik-01):// (https://github.com/gligli/anaglik-01)github (https://github.com/gligli/anaglik-01). (https://github.com/gligli/anaglik-01)com (https://github.com/gligli/anaglik-01)/ (https://github.com/gligli/anaglik-01)gligli (https://github.com/gligli/anaglik-01)/ (https://github.com/gligli/anaglik-01)anaglik (https://github.com/gligli/anaglik-01)-01 (https://github.com/gligli/anaglik-01)
2. A custom USB programmable wave data cartridge for the Yamaha RX5:
  https (https://github.com/gligli/rx5usb):// (https://github.com/gligli/rx5usb)github (https://github.com/gligli/rx5usb). (https://github.com/gligli/rx5usb)com (https://github.com/gligli/rx5usb)/ (https://github.com/gligli/rx5usb)gligli (https://github.com/gligli/rx5usb)/ (https://github.com/gligli/rx5usb)rx (https://github.com/gligli/rx5usb)5 (https://github.com/gligli/rx5usb)usb (https://github.com/gligli/rx5usb)

Before that I did a lot of embedded programming and hacking, from portable media players to modern video game consoles ( (http://gligli360.blogspot.fr/)http (http://gligli360.blogspot.fr/):// (http://gligli360.blogspot.fr/)gligli (http://gligli360.blogspot.fr/)360. (http://gligli360.blogspot.fr/)blogspot (http://gligli360.blogspot.fr/). (http://gligli360.blogspot.fr/)fr (http://gligli360.blogspot.fr/)/ (http://gligli360.blogspot.fr/) )

I started this project by making a PC emulator of the P600 digital hardware in order to learn how it worked -- and because at that point I didn't have a P600. Using a Z80 emulator library, the service manual and MiniSystem's blog, I was able to get it working to the point where I could see the CVs reacting to knob changes, envelopes and all...

Next, I scrapped the Z80 library and started writing my own C code which I compiled in a library and loaded in my P600 emulator/simulator so that it could do basic things like driving the analog synthesizer CVs, scanning the keyboard and displaying stuff on the 7-segment.

Then, I was lucky to find a mint P600 45 minutes from my town and bought it. Within a few hours, I had my C code working on it; I just had to write the Teensy low level pin interface, the rest was the same as in the simulator.

This was the point at which rewriting the firmware could really begin -- subsystem by subsystem -- including the envelopes, tuner, assigner, LFO. etc., until this version, which I hope you will enjoy as much using as I did while developing! At times it was painful too, but nothing even remotely ambitious is ever simple I guess... :)

The source code references and uses code developed by other synthesiser enthusiasts such as:

1. Tom Wiltshire of Electric (http://www.electricdruid.net/) (http://www.electricdruid.net/)Druid (http://www.electricdruid.net/) and his work on Direct Digital Synthesis based envelope generators and LFOs.
2. The XNOR (https://github.com/x37v/xnormidi) (https://github.com/x37v/xnormidi)MIDI (https://github.com/x37v/xnormidi) (https://github.com/x37v/xnormidi)Library (https://github.com/x37v/xnormidi) written by Alex Norman.
3. Jeff Lee of MiniSystem and his blog Prophet (http://prophet600.blogspot.com/) 600 (http://prophet600.blogspot.com/)Spirit (http://prophet600.blogspot.com/).
4. Bulghur of Motisonic (http://www.motisonic.com/) provided troubleshooting/testing and documentation.
5. Ramcur, Spetzle, Tohk, Wintermute303 (alpha testing)

###### Install the New Processor and Firmware

You will need the following items to complete this step:

1. Soldering iron, clamps, solder, 22awg or similar wire
2. Basic soldering skills
3. Understanding of where components are located in the Prophet 600.

Note: Before you begin, back up your sound patches as a SysEx dump. The firmware upgrade includes a feature to restore patches after the firmware has been run. Because the new system does not use the original memory in the Prophet 600, your original patches will be lost as soon as you upgrade.

Source the Teensy++ 2.0 USB Development Board. Two versions exist -- choose the version with the pins pre-soldered. You can source these from the following purveyor:

http (http://www.pjrc.com/store/teensypp_pins.html):// (http://www.pjrc.com/store/teensypp_pins.html)www (http://www.pjrc.com/store/teensypp_pins.html). (http://www.pjrc.com/store/teensypp_pins.html)pjrc (http://www.pjrc.com/store/teensypp_pins.html). (http://www.pjrc.com/store/teensypp_pins.html)com (http://www.pjrc.com/store/teensypp_pins.html)/ (http://www.pjrc.com/store/teensypp_pins.html)store (http://www.pjrc.com/store/teensypp_pins.html)/ (http://www.pjrc.com/store/teensypp_pins.html)teensypp (http://www.pjrc.com/store/teensypp_pins.html)_ (http://www.pjrc.com/store/teensypp_pins.html)pins (http://www.pjrc.com/store/teensypp_pins.html). (http://www.pjrc.com/store/teensypp_pins.html)html (http://www.pjrc.com/store/teensypp_pins.html)

Other sources exist.

###### Install Pin Jumpers

Minor changes must be made to the Teensy before installing it into the Prophet 600. Follow the directions below:

In the following steps, you will solder four wires connecting specific pins:

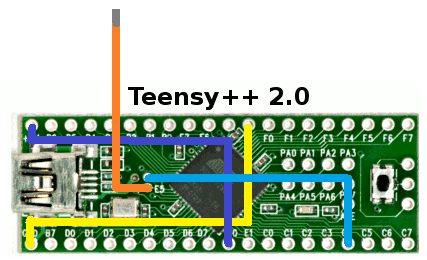
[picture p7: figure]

1. Solder the following wires onto the pins of the Teensy. They are colour coded for easy identification.
  1. GND to R: Yellow
  2. E0 to 5V: Violet
  3. E4 to C4: Blue
2. For the final Orange wire, cut a 6cm length and solder it into the E5 hole. Lightly tin the other end; it will be plugged into the socket on the Prophet 600 computer board. The Teensy should look something like the following:

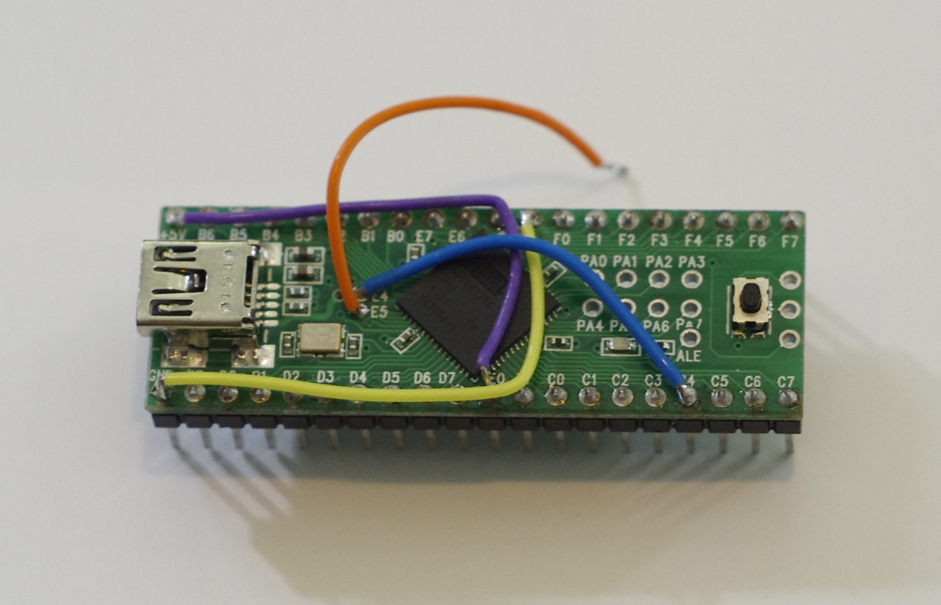
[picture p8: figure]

3. Cut pin 30 on the Teensy. Make sure the remains of it are as small as possible.

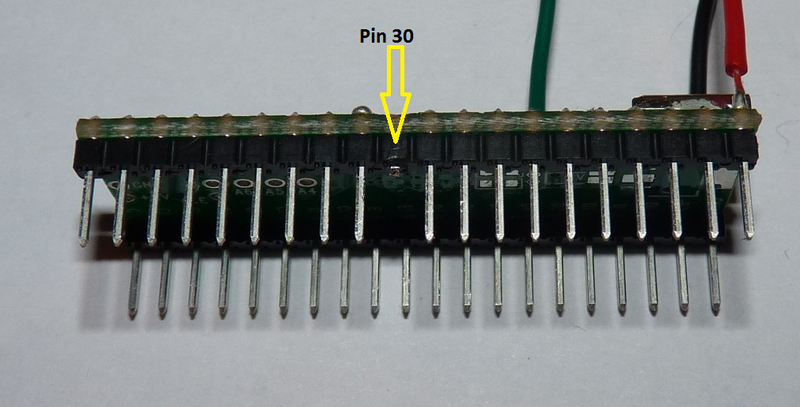
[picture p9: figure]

The Teensy is now ready to be flashed.

###### Flash the Teensy

Before you install the Teensy, you will flash the firmware on to the Teensy by completing the following steps:

1. Locate the firmware file in this archive (a .hex file).
2. Download the Teensy programmer from http (http://www.pjrc.com/teensy/teensy.exe):// (http://www.pjrc.com/teensy/teensy.exe)www (http://www.pjrc.com/teensy/teensy.exe). (http://www.pjrc.com/teensy/teensy.exe)pjrc (http://www.pjrc.com/teensy/teensy.exe). (http://www.pjrc.com/teensy/teensy.exe)com (http://www.pjrc.com/teensy/teensy.exe)/ (http://www.pjrc.com/teensy/teensy.exe)teensy (http://www.pjrc.com/teensy/teensy.exe)/ (http://www.pjrc.com/teensy/teensy.exe)teensy (http://www.pjrc.com/teensy/teensy.exe). (http://www.pjrc.com/teensy/teensy.exe)exe (http://www.pjrc.com/teensy/teensy.exe) and save it.
3. Launch the programmer by double clicking the teensy.exe application. It may ask you to confirm running the file. Select Run.
4. The flash application appears. Select File/Open HEX File and navigate to the location that you saved the p600firmware hex file and select it.
5. Connect the Teensy board to your computer via USB. The orange LED may light. Press the button on the Teensy. Immediately, the display on the Teensy application will change indicating that it is ready to transmit the file to the Teensy.
6. Select Operation/Program. The application will show a progress bar and indicate when the programming is complete.
7. Disconnect the Teensy from the USB cable.

The Teensy is now ready for one final modification before it is installed in the Prophet 600.

###### Remove 5Volt Connector

You must make one final modification to the Teensy before installing it in the Prophet 600.

1. Using a sharp knife -- such as an Xacto or other razor knife, cut the trace that connects the 5Vs from the adjacent pad. This terminates the +5V connection used to flash the board when not installed.

###### Install the Teensy into the Prophet 600

1. If you want to be able to restore the Z80 and your sounds to your Prophet 600, back-up all of your sounds as a SysEx file dump. There are several ways to do this; instructions to do this are available online.
2. Unplug and open the Prophet 600 and locate the computer board located on the bottom left side of the case next to the power transformer.
3. Locate the Z80 microprocessor on the lower left hand corner of the computer board and carefully remove it using an IC extractor or nudging it up on each side until it is loose enough to pull of of the socket. Store it in a safe place on conductive foam.

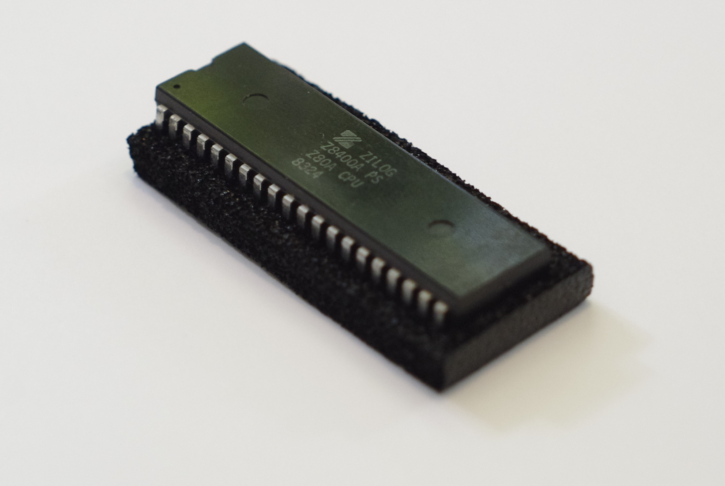
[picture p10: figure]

4. Install the Teensy with the USB connector facing toward the back of the Prophet 600 by seating it about halfway into the socket.
5. Plug the E5 wire into socket number 30 -- which will be open because it happens to be in exactly the same location that you cut the pin on the Teensy.
6. Push the Teensy down into the socket to seat it securely.
7. Inspect your work. Is the E5 wire properly connected? Is the Teensy oriented in the right direction? Your Teensy should look something like the following:
8. Plug in the Prophet 600 and switch it on and confirm that the unit is operating. The orange LED on the Teensy will light and the tune routine will commence stepping through the 12 oscillators and 6 filters; during the tune routine the display cycle A1 through A6, b1 through b6 and F1 through F6. After approximately 20-30 seconds, a welcome message will scroll.

Congratulations! You have just confirmed that you’ve successfully install the Prophet 600 Firmware Upgrade. Because the unit has no presets upon completion of these steps, take this moment to dial up a suitable sound on the Prophet 600 with the preset mode set to “off”. Take a few moments to dial up some basic sounds on the instrument. You will promptly declare this instrument to have been sonically liberated after 30 plus years in a 4MHz Z80 regime.

The next section explains how to initialise the unit and how to get the most from the upgrade.

###### Upgrading the Firmware

To flash the firmware, you will need to complete the following steps:

1. Make sure the Prophet 600 is turned off.
2. Press both “from tape” and “to tape”, and while keeping them pressed, turn on the Prophet 600.
3. The display should read “U”, the Prophet 600 is now in update mode and ready to receive a SysEx firmware upgrade.
4. Using MidiOx ( http://www.midiox.com/ ) or any SysEx tool of your choice, send the SysEx upgrade file to the Prophet 600 (the file should be “p600firmware.syx”). In MidiOx configuration, make sure “Delay Between Buffers” and “Delay After F7” are at least 250 Milliseconds and “Delay After F7” is checked. Some USB-MIDI interfaces may need more than 250 Milliseconds to work fine.
5. While the Prophet 600 is upgrading, the display will show a spinning segment.
6. If the upgrade ends with “S” on the display, the upgrade was successful, you can power cycle the Prophet 600 and use the new firmware.
7. If the upgrade ends with “E” on the display, the upgrade has failed, you have to do the upgrade procedure again until it succeeds. It is not advised to try to run the Prophet 600 in normal mode after a failed upgrade.

###### Resources

Project Site: http://gligli.github.io/p600fw/

Issues/Bugs: https (https://github.com/gligli/p600fw/issues):// (https://github.com/gligli/p600fw/issues)github (https://github.com/gligli/p600fw/issues). (https://github.com/gligli/p600fw/issues)com (https://github.com/gligli/p600fw/issues)/ (https://github.com/gligli/p600fw/issues)gligli (https://github.com/gligli/p600fw/issues)/ (https://github.com/gligli/p600fw/issues)p (https://github.com/gligli/p600fw/issues)600 (https://github.com/gligli/p600fw/issues)fw (https://github.com/gligli/p600fw/issues)/ (https://github.com/gligli/p600fw/issues)issues (https://github.com/gligli/p600fw/issues)

Teensy Site: http (http://www.pjrc.com/teensy/index.html):// (http://www.pjrc.com/teensy/index.html)www (http://www.pjrc.com/teensy/index.html). (http://www.pjrc.com/teensy/index.html)pjrc (http://www.pjrc.com/teensy/index.html). (http://www.pjrc.com/teensy/index.html)com (http://www.pjrc.com/teensy/index.html)/ (http://www.pjrc.com/teensy/index.html)teensy (http://www.pjrc.com/teensy/index.html)/ (http://www.pjrc.com/teensy/index.html)index (http://www.pjrc.com/teensy/index.html). (http://www.pjrc.com/teensy/index.html)html (http://www.pjrc.com/teensy/index.html)

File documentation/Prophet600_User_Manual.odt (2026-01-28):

GliGli’s Sequential Circuits Prophet 600 Firmware Upgrade

Table of Contents

###### User Manual / Getting Around the New Prophet 600

###### Review of New Features

The Prophet 600 Firmware Upgrade hosts the following improvements:

1. Easy-to-install non-destructive firmware drop-in replacement of the new firmware. If you ever find yourself pining for the old sound of your Prophet 600, you can remove the Teensy and restore the Z80.
2. Greater resolution of many of the sound parameters with an improved refresh rate that is making the instrument much more responsive.
3. Faster, smoother amplifier and filter envelope generators supporting four different modes:
  1. Fast Linear.
  2. Slow Linear.
  3. Fast Exponential.
  4. Slow Exponential.
4. A new LFO function generator with a wider range from one cycle every <20 seconds> to about 60Hz with four new waveforms in addition to the original triangle and square including sine, random stepped, noise (like on the original Prophet 5, but non-periodic) and sawtooth (ramp up).
5. A dedicated vibrato which can be controlled by the modulation wheel, or can start progressively after a fixed amount of time.
6. Multiple keyboard modes including last/low/high note priority.
7. Unison detune.
8. Mix Overdrive which now allows the output from both oscillators to drive the mix VCAs A and B harder as well as the Curtis 4 pole filter resulting in new sonic possibilities.
9. Pitch Wheel interval selection of plus/minus one octave, a whole tone, a minor third and a fifth.
10. Pitch Wheel reassignment to the VCF and Volume or off.
11. Modulation wheel intensity setting from Maximum to Medium to Minimum.
12. Full Midi In control including:
  1. Amp and Filter velocity sensitivity with an external keyboard controller.
  2. Continuous Controllers (CC) of all sound parameters.
  3. Program change (PC) to choose current preset.
  4. Synchronizing the arpeggiator to MIDI clock.
13. A new and improved tuning procedure.
14. Octave, chromatic and free Oscillator course pitch control.
15. Plus/Minus setting for Oscillator Fine Tune and Filter Envelope amount for Poly Mod and Filter.
16. Assignable, Random And Up/Down Arpeggiator.
17. Debounce feature that prevents unintended retriggering caused by the old keyboard.
18. Organised open source code available on GitHub: https (https://github.com/gligli/p600fw):// (https://github.com/gligli/p600fw)github (https://github.com/gligli/p600fw). (https://github.com/gligli/p600fw)com (https://github.com/gligli/p600fw)/ (https://github.com/gligli/p600fw)gligli (https://github.com/gligli/p600fw)/ (https://github.com/gligli/p600fw)p (https://github.com/gligli/p600fw)600 (https://github.com/gligli/p600fw)fw (https://github.com/gligli/p600fw)

###### Settings Pages

The Prophet 600 is now organised around two menu pages through which you configure the instrument.

1. The Additional Parameters Page is the default page in manual mode, and is active when pressing “to tape” in preset mode: This is the normal interaction page. The advanced sound parameters are found here such as selecting new LFO waveforms, envelope generator profiles and ranges of various controllers.
2. A Miscellaneous Settings Page active when “from tape” is kept pressed: This is the page used to access various “housekeeping” parameters such as setting MIDI channels and modes and so on.

###### Tune

Upon first power-up, the Prophet 600 tunes itself. The “Tune” light illuminates and the display indicates the oscillator or filter being tuned from A1 through A6, b1 through b6 and F1 through F6 for Oscillator A, B and the Filter respectively. The routine takes about 20 seconds to complete depending on the tuning of your instrument.

It is normal to have to retune the instrument during the first 30 minutes of operation as the electronics warm to a stable operating temperature. To tune, simply press the tuning button as required.

###### Manual/Preset Modes

As with the original Prophet 600 firmware, pressing the Preset button switches between manual mode, in which the synthesiser parameters sound parameters reflect the active sonic-state of the instrument, and preset mode in which the sound is a stored patch.

You can edit a stored patch or manual patch or preset patch at any time by completing the following:

1. Press the “Record” button on the keypad. It will blink.
2. Press the two digit location to which you want to save the patch.

The patch is saved. It will overwrite whatever sound patch was there before.

You can cancel a patch store any time while the “Record” button is blinking by pressing record.

###### Additional Parameters Page Quick Guide

Below is a table summarising the Parameters and keypad buttons required to access the synthesiser additional parameters. More detailed instructions are provided after the table summary.

To select a parameter, press one of the keypad numbers once or twice, its name and value will be displayed. To edit it, used the “Speed” knob.

###### Miscellaneous Settings Page Quick Guide

Below is a table summarising the keypad buttons required to access the synthesiser miscellaneous settings. More detailed instructions are provided after the table summary.

To access a function, maintain “from tape” pressed and press a keypad number.

###### Arpeggiator

The instrument supports three arpeggiator modes:

1. Arp Down/Up plays an up/down note sequence with double trigger on the lowest and highest note. For example, playing C3 C4 E4 G4 will play: C3 C4 E4 G4 G4 E4 C4 C3 C3 C4 and so on. Mathematically, it allows you to work out the time signature. Three notes results in ¾ time, notes 4/4 time, 5 notes in 5/4, etc. To play with the Arp Up/Down, press the Arp Dn/Up button on the keypad. The “Arp Dn/Up” will light continuously.
2. Arp Assignable sequences the notes in the order that they are played. To play with the Arp Assignable, press the “Arp Assign” button and play the notes in the order you want them sequenced. The “Arp Assign” will light continuously.
3. Arp Random plays notes played in a random order. To play the Arp Random, press the “Arp Assign” button twice until it blinks and then play the notes.

With all Arpeggiator modes, press the “Record” button on the keypad to latch or hold the notes played. Playing additional notes while in Record mode will latch addition notes to the existing sequence to a maximum of 128 notes. To clear the notes from the sequence, press the “Record” button to switch it off.

The speed is controlled by pressing “0” once on the additional parameters page and using the “Speed” knob to change it.

The foot switch input can be used to hold the arpeggiator.

###### Keyboard Modes

The Prophet 600 can be either in Polyphonic, Unison or Chord mode.

1. The synthesizer starts in Polyphonic mode, in which any new note will be assigned to one of the 6 voices.
2. If you switch “Unison track” on with no pressed key, you are in Unison mode, all 6 voices will play the same note.
3. If you switch “Unison track” on with one or more pressed keys, you are in Chord mode. The pattern those keys made will now be transposed over the whole keyboard range by new notes.

The foot switch input can be used to latch a new pattern of notes.

New notes will be assigned to voices using one of those priority rules:

1. “Last”: New notes will always play, the oldest notes may be stolen.
2. “Low”: Only the lowest notes will play. In Unison or Chord mode, legato will be active.
3. “High”: Only the highest notes will play. In Unison or Chord mode, legato will be active.

The assignment priority is controlled by pressing “7” twice on the additional parameters page and using the “Speed” knob to change it.

###### New Behaviour for Knobs

###### Value Display

When you turn any knob, its value will now be shown on the 7-segment display.

That value will always go from 0 to 255. The display being only 2 digits, the decimal dot is used to show hundreds (no dot for 0-99, steady dot for 100-199, blinking dot for 200-255).

The knob true resolution can be greater than 0-255 (8bits) to ensure smooth sound changes.

###### Oscillator A and B Mix

A new feature has been introduced that allows the VCAs into the filter to be over-driven by Oscillator A and B. In order to support this, the Oscillator A/B Mix has been reassigned to the Oscillator A Level and the Glide knob now controls the Oscillator B Level. The normalised point is at about half way or 5 on the dial. To overdrive the inputs, go all the way to 10. Because of this, the Glide speed has been reassigned to the “Glide” additional parameter (press “7” once on the additional parameters page).

Negative Values

The Poly Mod Filter Amount, the Filter Amount and the Detune knobs are now zero set to the midway position to allow both positive and negative values. This means that inverse envelopes can be applied to the modulations and filter controls and it is now possible to detune Oscillator B flat as well as sharp with respect to Oscillator A.

###### Low Frequency Oscillator

###### LFO Waveform

The Prophet 600 now supports six waveforms in addition to the standard Triangle and Square waves including Sine, (Saw) Ramp Up, Random, Noise. To select the desired waveform:

1. For Triangle, Sine or Saw:
  1. If you are in preset mode, make sure “to tape” is lit, else press it to access the additional parameters page.
  2. Switch the LFO-MOD Shape button to Triangle.
  3. Press the “1” button once and use the “Speed” knob to select the Triangle, Sine or Saw. The display indicates the current selection.
1. For Square, Random or Noise:
  1. If you are in preset mode, make sure “to tape” is lit, else press it to access the additional parameters page.
  2. Switch the LFO-MOD Shape button to Square.
  3. Press the “1” button once and use the “Speed” knob to select the Square, Random or Noise. The display indicates the current selection.

###### LFO Speed

You can control the speed range of the LFO from Slow; the default setting; to Fast by pressing “1” once on the additional parameters page and using the “Speed” knob to select either Slow of Fast.

LFO Target

You can choose to assign the LFO to only one of the two oscillators by pressing “1” twice on the additional parameters page and using the “Speed” knob to select either Oscillator A, Oscillator B or both as a target.

Vibrato

The Prophet 600 now features a dedicated pitch vibrato. You can adjust its speed by pressing “2” once and its amount by pressing “3” once on the additional parameters page.

By default, it is controlled by a modulation delay which can be adjusted by pressing “4” once on the additional parameters page.

Pitch Wheel

The Pitch Wheel Range and Assignment can now be selected and, if required, the Pitch Wheel can be calibrated.

###### Pitch Wheel Range

The range of the Pitch Wheel can be set to Octave, Fifth, Minor Third or Second. To set the Pitch Wheel range press the “6” twice on the additional parameters page and use the “Speed” knob to select it.

###### Pitch Wheel Assignment

The Pitch Wheel can be assigned to the control the Pitch (the default setting), the Filter Cutoff Frequency, Volume or Off. To select the Pitch Wheel assignment press the “6” once on the additional parameters page and use the “Speed” knob.

###### Pitch Wheel Calibration

The Pitch Wheel might need to be calibrated to its center position to properly sweep the full range selected. To calibrate the Pitch Wheel:

1. Center the Pitch Wheel.
2. While maintaining “from tape” pressed Press the “3” button on the keypad. The display will indicate that the Pitch Wheel has been calibrated.

###### Modulation Wheel

###### Wheel Depth

The range of the Modulation wheel can be set for Full, High, Half or Minimum to control the depth of modulation over the range of the wheel. To set the Modulation Wheel depth press the “3” once on the additional parameters page and use the “Speed” knob to select it.

Wheel Target

The Modulation wheel can either control the LFO or the Vibrato, the other being controlled by the modulation delay. Pressing “4” twice on the additional parameters page and using the “Speed” knob changes this.

###### Modulation Delay

The modulation delay can be adjusted by pressing “4” once on the additional parameters page.

###### Envelope Generator Mode

Four Envelope Generator (EG) modes are supported for both the Amplifier and the Filter: Fast Linear, Slow Linear and Fast Exponential and Slow Exponential which controls the response of the slope of the rise and fall of the attack, decay and release phase. To select the desired response:

For the Amplifier EG:

1. If you are in preset mode, make sure “to tape” is lit, else press it to access the additional parameters page.
2. Press the “5” once on the additional parameters page and use the “Speed” knob to select it.

For the Filter EG:

1. If you are in preset mode, make sure “to tape” is lit, else press it to access the additional parameters page.
2. Press the “5” twice on the additional parameters page and use the “Speed” knob to select it.

###### Oscillator Range Control

Oscillator A and B frequency ranges are now controllable in three modes: Octave (the default value), Chromatic and Free. The range remains the same but it is now possible to sweep the frequency of the oscillators with a greater or smaller degree of fine control. To select the oscillator sweep mode, press button “8” twice on the additional parameters page and use the “Speed” knob to select it.

Midi Channels

Miscellaneous Settings function “1” selects the MIDI receive channel, it can be “OMNI” to receive on all channels.

Miscellaneous Settings function “2” selects the MIDI send channel. The Prophet 600 will transmit note on / note off from the keyboard or the arpeggiator, plus pitch bend wheel and modulation wheel changes.

Voice Defeat

One or more voices from the Prophet 600 can be turned off. This can be useful if e.g. they aren’t working fine.

Use Miscellaneous Settings function “5” to select a voice number from 1 to 6, and function “6” to turn it on or off.

Synchronisation source

Miscellaneous Settings function “8” allows for one of three synchronization sources to be selected for the arpeggiator:

1. Internal: this is the default setting, the Prophet 600 will generate its own clock.
2. MIDI: a fraction of the incoming MIDI clock will be used to clock the arpeggiator.
3. Tape: you can plug any pulse clock source on the “Cassette in” jack. A fraction of it will be used to clock the arpeggiator.

###### Managing Sound Libraries through SysEx

###### Loading

Loading a SysEx library will overwrite your existing stored patches. To load a complete SysEx Library:

1. Connect the instrument via MIDI.
2. Load the SysEx file into a utility or into your sequencer application. Good utilities include:
  1. Windows: http (http://www.midiox.com/):// (http://www.midiox.com/)www (http://www.midiox.com/). (http://www.midiox.com/)midiox (http://www.midiox.com/). (http://www.midiox.com/)com (http://www.midiox.com/)/ (http://www.midiox.com/)
  2. OSX: http (http://www.snoize.com/SysExLibrarian/):// (http://www.snoize.com/SysExLibrarian/)www (http://www.snoize.com/SysExLibrarian/). (http://www.snoize.com/SysExLibrarian/)snoize (http://www.snoize.com/SysExLibrarian/). (http://www.snoize.com/SysExLibrarian/)com (http://www.snoize.com/SysExLibrarian/)/ (http://www.snoize.com/SysExLibrarian/)SysExLibrarian (http://www.snoize.com/SysExLibrarian/)/ (http://www.snoize.com/SysExLibrarian/)
3. Determine the appropriate transmission channel of the SysEx utility or sequencer application.
4. Set the Prophet 600 receive channel to the same channel that the SysEx will be transmitted by either selecting the specific channel or simply selecting OMNI (receive on all channels).
5. Transmit the data to the instrument.

Saving

Miscellaneous Settings function “6” will send a SysEx dump of all presets on MIDI out. Use your favourite SysEx utility to store it.

###### Troubleshooting and Bugs

This version of the firmware has been tested on many Prophet 600s. Issues may still arise in an instrument manufactured over 30 years ago operating in varied environments; components age unevenly. We invite you to submit issues and bugs but understand that in some cases issues might have to do more with the physical characteristics of the instrument than with software. Here are couple of things to think about:

1. Switch the instrument off, think of your grammar school teacher and then switch it back on again. Often, this all that is needed to restore the instrument.
2. Check your MIDI is properly set-up. Is it transmitting messages that might be causing the instrument to misbehave. Filter those messages.
3. Check for a new hex file for an updated firmware version.
4. How did the instrument operate before the upgrade? If the instrument becomes unstable, restore the original Z80 and observe the behaviour.
5. Power Supply: Unstable power supplies can cause a lot of issues with digital/analogue hybrid synthesisers.
6. Locked or unstable parameters: Pots can generate unstable voltages that toggle between two states. This was not an issue when the resolution on the Prophet 600 was lower, say four or six bits. However, with higher depth resolution, you might hear the artefacts of dirty or faulty pots causing slight wavering in the sound. Particularly susceptible parameters include the Pulse Width and the Filter Cutoff with a high Resonance setting. The solution is to clean the pot, change it or move the pot to a new location. You can also use a MIDI controller to set values and then store them.
7. Keep abreast of changes and report issues at Github-Issues: https (https://github.com/gligli/p600fw/issues):// (https://github.com/gligli/p600fw/issues)github (https://github.com/gligli/p600fw/issues). (https://github.com/gligli/p600fw/issues)com (https://github.com/gligli/p600fw/issues)/ (https://github.com/gligli/p600fw/issues)gligli (https://github.com/gligli/p600fw/issues)/ (https://github.com/gligli/p600fw/issues)p (https://github.com/gligli/p600fw/issues)600 (https://github.com/gligli/p600fw/issues)fw (https://github.com/gligli/p600fw/issues)/ (https://github.com/gligli/p600fw/issues)issues (https://github.com/gligli/p600fw/issues).

###### Appendix

###### MIDI Implementation

Two types of MIDI controllers are implemented:

1. Continuous parameters: 0-16383 using 2 CCs, or 0-127 using only the coarse one.
2. Stepped parameters: 0-127, variable number of steps. They work by dividing the 0-127 range is as many zones as there is choices for the parameter. E.g.: "Unison" is off for 0-63 and on for 64-127.

The Prophet 600 receives Continuous Controllers in Preset mode only.

###### Resources

Project Site: http://gligli.github.io/p600fw/

Issues/Bugs: https (https://github.com/gligli/p600fw/issues):// (https://github.com/gligli/p600fw/issues)github (https://github.com/gligli/p600fw/issues). (https://github.com/gligli/p600fw/issues)com (https://github.com/gligli/p600fw/issues)/ (https://github.com/gligli/p600fw/issues)gligli (https://github.com/gligli/p600fw/issues)/ (https://github.com/gligli/p600fw/issues)p (https://github.com/gligli/p600fw/issues)600 (https://github.com/gligli/p600fw/issues)fw (https://github.com/gligli/p600fw/issues)/ (https://github.com/gligli/p600fw/issues)issues (https://github.com/gligli/p600fw/issues)

Teensy Site: http (http://www.pjrc.com/teensy/index.html):// (http://www.pjrc.com/teensy/index.html)www (http://www.pjrc.com/teensy/index.html). (http://www.pjrc.com/teensy/index.html)pjrc (http://www.pjrc.com/teensy/index.html). (http://www.pjrc.com/teensy/index.html)com (http://www.pjrc.com/teensy/index.html)/ (http://www.pjrc.com/teensy/index.html)teensy (http://www.pjrc.com/teensy/index.html)/ (http://www.pjrc.com/teensy/index.html)index (http://www.pjrc.com/teensy/index.html). (http://www.pjrc.com/teensy/index.html)html (http://www.pjrc.com/teensy/index.html)

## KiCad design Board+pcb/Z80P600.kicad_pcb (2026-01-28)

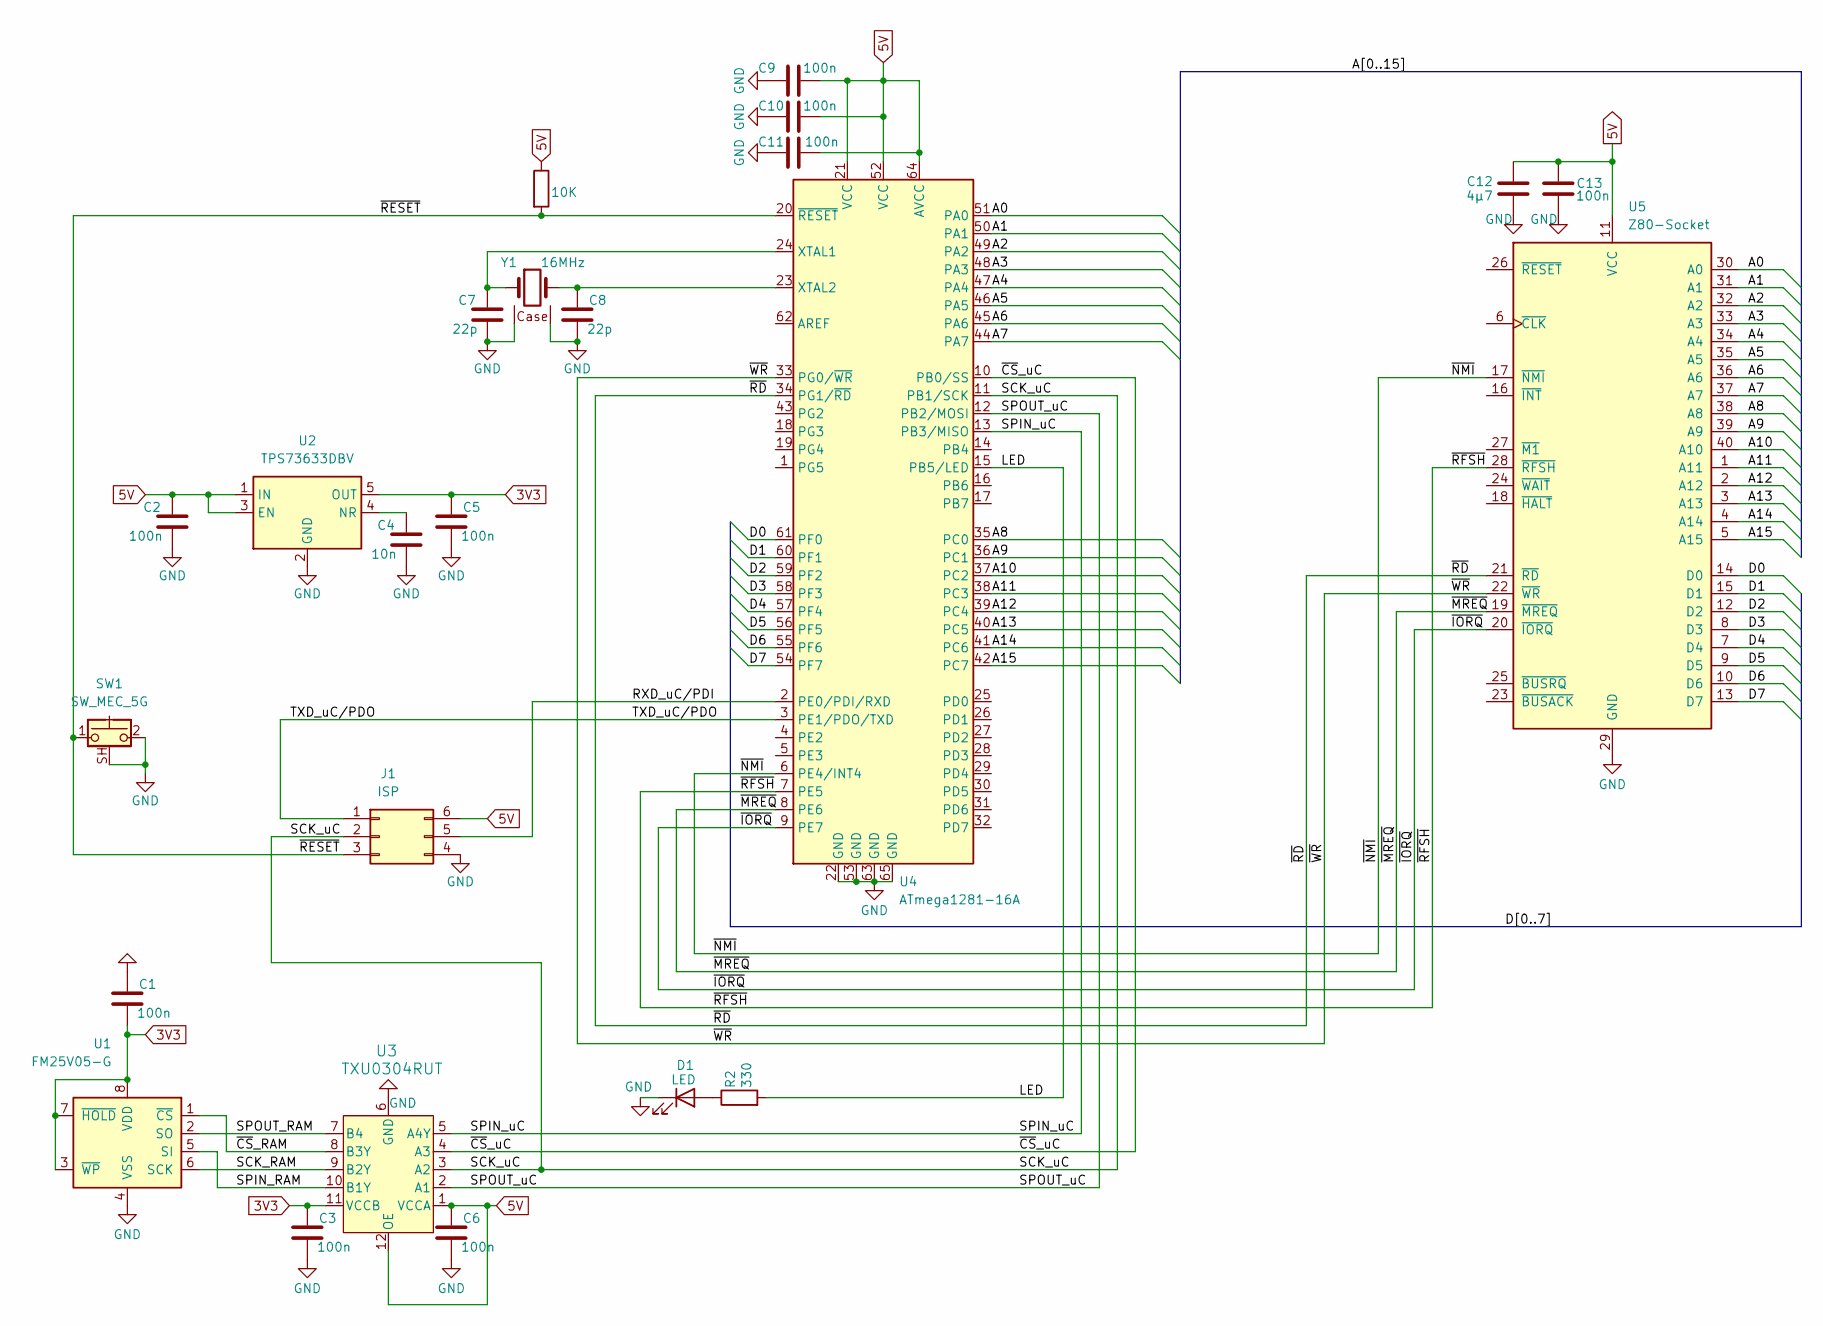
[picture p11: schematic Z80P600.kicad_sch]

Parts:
C1, C2, C3, C5, C6, C9, C10, C11, C13: 100n; C_0402_1005Metric
C4: 10n; C_0402_1005Metric
C7, C8: 22p; C_0402_1005Metric
C12: 4µ7; C_0805_2012Metric
D1: LED; LED_0603_1608Metric_Pad1.05x0.95mm_HandSolder
J1: ISP; PinHeader_2x03_P2.54mm_Vertical
R1: 10K; R_0402_1005Metric
R2: 330; R_0402_1005Metric
SW1: SW_MEC_5G; SW_Push_1P1T-SH_NO_CK_KMR2xxG
U1: FM25V05-G; SOIC-8_3.9x4.9mm_P1.27mm
U2: TPS73633DBV; SOT-23-5
U3: TXU0304RUT; Texas_R-PUQFN-N12
U4: ATmega1281-16A; QFN-64-1EP_9x9mm_P0.5mm_EP7.65x7.65mm_ThermalVias
U5: Z80-Socket; Z80_DIP-40_SMDSocket
Y1: 16MHz; Crystal_SMD_2520-4Pin_2.5x2.0mm

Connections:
3V3: C1.2, C3.1, C5.1, U1.3 (~WP), U1.7 (~HOLD), U1.8 (VDD), U2.5 (OUT), U3.11 (VCCB)
5V: C2.1, C6.1, C9.1, C10.1, C11.1, C12.1, C13.1, J1.6 (VCC), R1.1, U2.1 (IN), U2.3 (EN), U3.1 (VCCA), U3.12 (OE), U4.21 (VCC), U4.52 (VCC), U4.64 (AVCC), U5.11 (VCC)
/A0: U4.51 (PA0), U5.30 (A0)
/A1: U4.50 (PA1), U5.31 (A1)
/A2: U4.49 (PA2), U5.32 (A2)
/A3: U4.48 (PA3), U5.33 (A3)
/A4: U4.47 (PA4), U5.34 (A4)
/A5: U4.46 (PA5), U5.35 (A5)
/A6: U4.45 (PA6), U5.36 (A6)
/A7: U4.44 (PA7), U5.37 (A7)
/A8: U4.35 (PC0), U5.38 (A8)
/A9: U4.36 (PC1), U5.39 (A9)
/A10: U4.37 (PC2), U5.40 (A10)
/A11: U4.38 (PC3), U5.1 (A11)
/A12: U4.39 (PC4), U5.2 (A12)
/A13: U4.40 (PC5), U5.3 (A13)
/A14: U4.41 (PC6), U5.4 (A14)
/A15: U4.42 (PC7), U5.5 (A15)
/D0: U4.61 (PF0), U5.14 (D0)
/D1: U4.60 (PF1), U5.15 (D1)
/D2: U4.59 (PF2), U5.12 (D2)
/D3: U4.58 (PF3), U5.8 (D3)
/D4: U4.57 (PF4), U5.7 (D4)
/D5: U4.56 (PF5), U5.9 (D5)
/D6: U4.55 (PF6), U5.10 (D6)
/D7: U4.54 (PF7), U5.13 (D7)
/LED: R2.2, U4.15 (PB5/LED)
/RXD_uC/PDI: J1.5 (PDI), U4.2 (PE0/PDI/RXD)
/SCK_RAM: U1.6 (SCK), U3.9 (B2Y)
/SCK_uC: J1.2 (SCK), U3.3 (A2), U4.11 (PB1/SCK)
/SPIN_RAM: U1.5 (SI), U3.10 (B1Y)
/SPIN_uC: U3.5 (A4Y), U4.13 (PB3/MISO)
/SPOUT_RAM: U1.2 (SO), U3.7 (B4)
/SPOUT_uC: U3.2 (A1), U4.12 (PB2/MOSI)
/TXD_uC/PDO: J1.1 (PDO), U4.3 (PE1/PDO/TXD)
/~CS_RAM: U1.1 (~CS), U3.8 (B3Y)
/~CS_uC: U3.4 (A3), U4.10 (PB0/SS)
/~IORQ: U4.9 (PE7), U5.20 (~IORQ)
/~MREQ: U4.8 (PE6), U5.19 (~MREQ)
/~NMI: U4.6 (PE4/INT4), U5.17 (~NMI)
/~RD: U4.34 (PG1/~RD), U5.21 (~RD)
/~RESET: J1.3 (~RST), R1.2, SW1.1, U4.20 (~RESET)
/~RFSH: U4.7 (PE5), U5.28 (~RFSH)
/~WR: U4.33 (PG0/~WR), U5.22 (~WR)
GND: C1.1, C2.2, C3.2, C4.2, C5.2, C6.2, C7.2, C8.2, C9.2, C10.2, C11.2, C12.2, C13.2, D1.1 (K), J1.4 (GND), SW1.2, SW1.SH (B), U1.4 (VSS), U2.2 (GND), U3.6 (GND), U4.22 (GND), U4.53 (GND), U4.63 (GND), U4.65 (GND), U5.29 (GND), Y1.2 (Case), Y1.4 (Case)
unnamed: D1.2 (A), R2.1
unnamed: C4.1, U2.4 (NR)
unnamed: C7.1, U4.24 (XTAL1), Y1.1
unnamed: C8.1, U4.23 (XTAL2), Y1.3

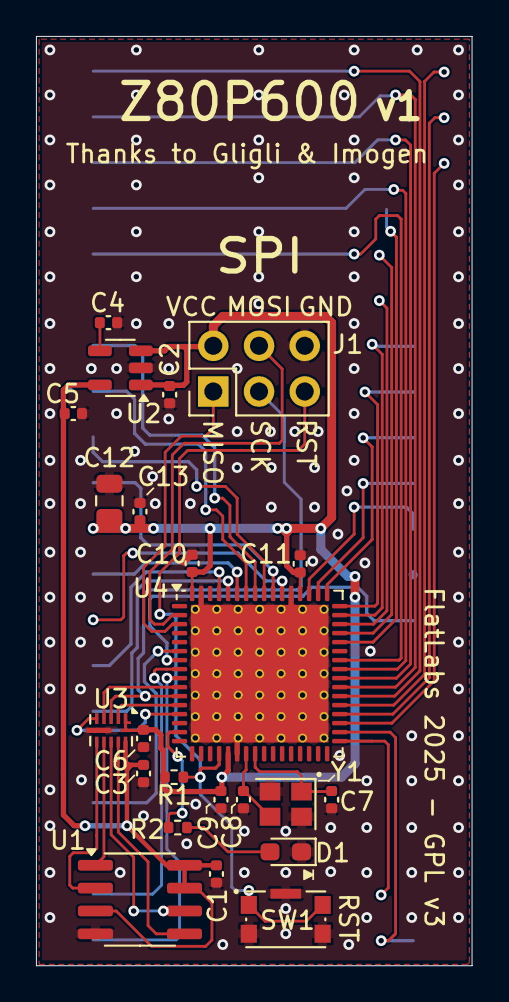
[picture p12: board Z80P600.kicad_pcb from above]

Board: 2 copper layers, 24.2 x 51.6 mm, 24 parts (1 on the bottom side), 49 nets.

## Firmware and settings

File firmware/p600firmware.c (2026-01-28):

#include <avr/io.h>
#include <avr/boot.h>
#include <avr/pgmspace.h>
#include <avr/interrupt.h>
#include <util/delay.h>
#include <util/crc16.h>
#include <string.h>

#include "Z80P600.h"
#include "spi_fram.h"

#include "synth.h"

#define CLOBBERED(reg)	__asm__ __volatile__ ("" : : : reg);

#define CPU_PRESCALE(n)	(CLKPR = 0x80, CLKPR = (n))
#define CPU_16MHz       0x00
#define CPU_8MHz        0x01
#define CPU_4MHz        0x02
#define CPU_2MHz        0x03
#define CPU_1MHz        0x04
#define CPU_500kHz      0x05
#define CPU_250kHz      0x06
#define CPU_125kHz      0x07
#define CPU_62kHz       0x08

#define MEMZONE		0		//	/MREQ = 0	/RFSH = 1	/IORQ = 1
#define IOZONE		1		//	/MREQ = 1	/RFSH = 0	/IORQ = 0

// Writes to synth hardware

static FORCEINLINE void hardware_write(int8_t io, uint16_t addr, uint8_t data)
{
 // equivalent to setIdle(1);
	WR_PORT |= (1 << Z80_WR) | (1 << Z80_RD);  // /WR and /RD both high
	SIGNAL_PORT = (SIGNAL_PORT | (1 << Z80_MREQ)) & ~(1 << Z80_RFSH); // /RFSH = 0, /MREQ = 1 and /IORQ untouched
	
 // Prepare write : Data port as output
	DATA_DDR = 0xFF;

	switch (io) {
		case MEMZONE:	// io = 0 ->  /IORQ to 1 end /MREQ to 0
			SIGNAL_PORT = (SIGNAL_PORT | (1 << Z80_IORQ)) & ~(1 << Z80_MREQ);
		break;
		
		case IOZONE:	// io = 1 ->  /IORQ to 0 and /MREQ to 1 
			SIGNAL_PORT = (SIGNAL_PORT | (1 << Z80_MREQ)) & ~(1 << Z80_IORQ);
		break;
	}
		
 // Transfer data to port
	DATA_PORT = data;
	
 // Split 16-bit address into two bytes and output them on the ports
	HI_ADDR_PORT = (uint8_t) ((addr & 0xFF00) >> 8); 	// High byte on port C
	LO_ADDR_PORT = (uint8_t)  (addr & 0x00FF); 			// Low byte on port A
		
 // /RFSH = 1 and /WR = 0 (to write the data)
	SIGNAL_PORT = SIGNAL_PORT | (1 << Z80_RFSH); // /RFSH = 1
	WR_PORT &= ~(1 << Z80_WR);  
}

// Reads from synth hardware

static FORCEINLINE uint8_t hardware_read(int8_t io, uint16_t addr)
{
	uint8_t value;

 // equivalent to setIdle(1);
 	WR_PORT |= (1 << Z80_WR) | (1 << Z80_RD); // /WR and /RD both high
    SIGNAL_PORT = (SIGNAL_PORT | (1 << Z80_MREQ)) & ~(1 << Z80_RFSH); // /RFSH = 0, /MREQ = 1 and /IORQ untouched
	
 // Prepare read : Data port as input
	DATA_DDR = 0x00;

	switch (io) {
		case MEMZONE:	// io = 0 ->  /IORQ to 1 end /MREQ to 0
			SIGNAL_PORT = (SIGNAL_PORT | (1 << Z80_IORQ)) & ~(1 << Z80_MREQ);
		break;
		
		case IOZONE:	// io = 1 ->  /IORQ to 0 and /MREQ to 1 
			SIGNAL_PORT = (SIGNAL_PORT | (1 << Z80_MREQ)) & ~(1 << Z80_IORQ);
		break;
	}

 // Split 16-bit address into two bytes and output them on the ports
	HI_ADDR_PORT = (uint8_t) ((addr & 0xFF00) >> 8); 	// High byte on port C
	LO_ADDR_PORT = (uint8_t)  (addr & 0x00FF); 			// Low byte on port A

	SIGNAL_PORT = SIGNAL_PORT | (1 << Z80_RFSH); // /RFSH = 1
	WR_PORT &= ~(1 << Z80_RD);  				 // /RD to 0 (to read the data)

	CYCLE_WAIT(2);	//  Wait a bit

 // read data
	value = DATA_PINS;

 // Toggle back /WR and /RD high
 // equivalent to setIdle(0)
	WR_PORT |= (1 << Z80_WR) | (1 << Z80_RD);  
	SIGNAL_PORT = (SIGNAL_PORT | (1 << Z80_IORQ)) & ~(1 << Z80_RFSH); // /RFSH = 0, /IORQ = 1 and /MREQ untouched
	
 // Return to default: Data port as output
	DATA_DDR = 0xFF;

	return value;
}

// Write routines (mem, io, uart)
FORCEINLINE void mem_write(uint16_t address, uint8_t value)
{
	hardware_write(0, address, value);
}
FORCEINLINE void io_write(uint8_t address, uint8_t value)
{
	hardware_write(1, address, value);
}

// Read routines (mem, io, uart)
FORCEINLINE uint8_t mem_read(uint16_t address)
{
	return hardware_read(0, address);
}
FORCEINLINE uint8_t io_read(uint8_t address)
{
	return hardware_read(1, address);
}

FORCEINLINE int8_t hardware_getNMIState(void)
{
	return !(SIGNAL_PINS & (1 << Z80_NMI));
}

static FORCEINLINE void hardware_init(int8_t ints)
{
 
 // Z80P600 board pinout
 //
 // MSB -> LSB (NC = No Connection)
 // Port A : A7-A0  (Out)
 // Port B : NC, NC, LED (Out, active High), NC, /RAM_SPI_OUT (in to µC), /RAM_SPI_IN (out from µC), /RAM_SPI_CLK (Out), /RAM_SPI_CS (Out) 
 // Port C : A15-A8 (Out)
 // Port D : D7-D0 (In/Out)
 // Port E : /RFSH (Out), /IORQ (Out), /MREQ (Out), /NMI (In, mapped to INT4), NC, NC, PDO (Out), PDI (In)
 // Port F : Unused
 // Port G : NC, NC, NC, NC, NC, NC, /RD, /WR

 // Init Port Direction Registers and Values
	LO_ADDR_DDR = 0xFF; 							// Low Addresses = Out
	HI_ADDR_DDR = 0xFF;	 							// High Addresses = Out
	DATA_DDR    = 0xFF; 							// Data Lines as output for the moment
		
	SPI_DDR     = 0xFF & ~(1 << MISO); 				// Only SPI_IN as input
	WR_DDR      = 0xFF; 							// All outputs
		
	SIGNAL_DDR  = 0xFF & ~(1 << Z80_NMI);			// Signal port : All outputs except /NMI

	UNUSED_DDR  = 0x00; 							// Unused Ports -> out
	UNUSED_PORT = 0xFF; 							// Pullups on unused Ports
		
 // Init Port Values		
	LO_ADDR_PORT = 0x00;							// Low address = 0
	HI_ADDR_PORT = 0x00;							// High address = 0
	DATA_PORT    = 0x00;							// Data byte to 0

	SPI_PORT = 0x00 | (1 << LED) | (1 << CS);		// Led On and /CS high

	SIGNAL_PORT = ~(1 << Z80_NMI);					// All signals to 1 (Inactive) except /NMI (input)

	WR_PORT = 0xFF;									// /WR & /RD high (Inactive)

 // Init SPI stuff for F-RAM
	SPI_init(SPI_F4); 	// SPI Clock @ 4MHz (up to 40MHz according to FM25V05 datasheet)
	
	if (ints)
	{
		// prepare a 2Khz interrupt

		OCR0A = 124;
		TCCR0A |= (1 << WGM01); 				//Timer 0 Clear-Timer on Compare (CTC) 
		TCCR0B |= (1 << CS01) | (1 << CS00);	//Timer 0 prescaler = 64
		TIMSK0 |= (1 << OCIE0A); 				//Enable overflow interrupt for Timer0

#ifdef UART_USE_HW_INTERRUPT	
		EIMSK |= (1 << INT4); 	// enable INT4
//		EICRB  = 0x00;			// Low level on INT4 triggers the interrupt
#else
		// prepare a 5Khz interrupt

		OCR2A = 49;
		TCCR2A |= (1 <<WGM21); 	//Timer 2 Clear-Timer on Compare (CTC) 
		TCCR2B |= (1 <<CS22);  	//Timer 2 prescaler = 64
		TIMSK2 |= (1 <<OCIE2A); //Enable overflow interrupt for Timer2
#endif	
	}

	hardware_read(0,0); // init r/w system
}

// Writes to F-RAM
void storage_write(uint32_t pageIdx, uint8_t *buf)
{
	if(pageIdx < (STORAGE_SIZE/STORAGE_PAGE_SIZE))
		SPI_write_page(pageIdx, &buf[0]);
}

// Reads from F-RAM
void storage_read(uint32_t pageIdx, uint8_t *buf)
{
	if(pageIdx < (STORAGE_SIZE/STORAGE_PAGE_SIZE))
		SPI_read_page(pageIdx, &buf[0]);
}

#define NRWW_SECTION(sec) __attribute__((section (sec))) __attribute__((noinline)) __attribute__((optimize ("O1"))) __attribute__((used))

void NRWW_SECTION(".bootspace") boot_program_page (uint32_t page, uint8_t *buf)
{
	uint16_t i;
	uint8_t sreg;

	// Disable interrupts.

	sreg = SREG;
	cli();

	eeprom_busy_wait ();

//	blHack_page_erase (page);
	boot_page_erase (page);
	boot_spm_busy_wait ();      // Wait until the memory is erased.

	for (i=0; i<SPM_PAGESIZE; i+=2)
	{
		// Set up little-endian word.

		uint16_t w = *buf++;
		w += (*buf++) << 8;

        boot_page_fill (page + i, w);
//		blHack_page_fill (page + i, w);
	}

//	blHack_page_write (page);     // Store buffer in flash page.
	boot_page_write (page);     // Store buffer in flash page.
	boot_spm_busy_wait();       // Wait until the memory is written.

	// Re-enable RWW-section again. We need this if we want to jump back
	// to the application after bootloading.

//	blHack_rww_enable ();
	boot_rww_enable ();

	// Re-enable interrupts (if they were ever enabled).

	SREG = sreg;
}


static int16_t NRWW_SECTION(".nrww_misc") getMidiByte(void)
{
	uint8_t data,status;

	CYCLE_WAIT(4);

//	while(PINC&0x10) // wait for NMI

	while (SIGNAL_PINS & (1 << Z80_NMI)) // wait for NMI
		CYCLE_WAIT(1);
	
	status = hardware_read(0, 0xe000); // read UART status
	CYCLE_WAIT(4);

	if ((status & 0b10110001) != 0b10000001) // detect errors
		return -1;

	data = hardware_read(0, 0xe001); // get byte
	CYCLE_WAIT(4);
	
	return data;
}

static uint16_t NRWW_SECTION(".nrww_misc") updateCRC(uint16_t crc,uint8_t data)
{
	return _crc_xmodem_update(crc, data);
}

#define UPDATER_GET_BYTE { b = getMidiByte(); if (b < 0) break; }
#define UPDATER_WAIT_BYTE(waited) { UPDATER_GET_BYTE; if(b!=(waited)) break; }
#define UPDATER_CRC_BYTE { UPDATER_GET_BYTE; crc=updateCRC(crc,b); }

void NRWW_SECTION(".updater") updater_main(void)
{
	int8_t i,needUpdate,success=0;
	uint8_t seg=1;
	int16_t b;
	uint16_t crc,pageIdx,pageSize,crcSent,byteIdx;
	uint8_t awaiting[4];
	static uint8_t page[SPM_PAGESIZE];
	
	// power supply still ramping up voltage	
	
	_delay_ms(100); // actual delay 800 ms

	// no interrupts while we update
	
	cli();
	
	// initialize low level

	hardware_init(0);
	
	// check if we need to go to update mode ("from tape" & "to tape" pressed)
	
	hardware_write(1,CSO0,0x01);
	CYCLE_WAIT(10);
	needUpdate = (hardware_read(1,CSI1)&0xc0)==0xc0;
	CYCLE_WAIT(10);
	needUpdate &= (hardware_read(1,CSI1)&0xc0)==0xc0;
	CYCLE_WAIT(10);
	
	if(!needUpdate)
		return;
	
	// select left 7seg 
	
	hardware_write(1,CSO0,0x20);
	CYCLE_WAIT(8);
	
	// show 'U'
	
	hardware_write(1,CSO1,0x3e);
	CYCLE_WAIT(8);
	
	// unclear NMI (UART IRQ)
	
	hardware_write(1,CS06,0b00110001);
	CYCLE_WAIT(8);

	// init 6850
	
	hardware_write(0,0x6000,0b00000011); // master reset
	MDELAY(1);
	
	hardware_write(0,0x6000,0b10010101); // clock/16 - 8N1 - receive int
	CYCLE_WAIT(8);
	
	hardware_read(0,0xe000); // read status & data to start the device
	CYCLE_WAIT(4);
	hardware_read(0,0xe001);
	CYCLE_WAIT(4);

	// main loop
	
	for(;;)
	{
		// init
		crc=0;
		
		// wait for sysex begin
		UPDATER_GET_BYTE;
		if (b != 0xf0) // "F0" is the SysEx start byte, so loop until that arrives
			continue;
		
		// check for my ID
		UPDATER_WAIT_BYTE(SYSEX_ID_0)
		UPDATER_WAIT_BYTE(SYSEX_ID_1)
		UPDATER_WAIT_BYTE(SYSEX_ID_2) 
		
		// check for update command
		UPDATER_WAIT_BYTE(SYSEX_COMMAND_UPDATE_FW) 
		
		// get page size, 0 indicates end of transmission
		UPDATER_CRC_BYTE
		pageSize = (b & 0x7f) << 7;
		UPDATER_CRC_BYTE
		pageSize |= b & 0x7f;
		
		if(pageSize!=SPM_PAGESIZE) // the last SysEx block comes with pagesize =0 and marks the end of the firmware stream
		{
			success=pageSize==0;
			break;
		}
		
		// get page ID
		UPDATER_CRC_BYTE
		pageIdx= (b & 0x7f) << 7;
		UPDATER_CRC_BYTE
		pageIdx |= b & 0x7f;
		
		// get data
		byteIdx = 0;
		for(i = 0; i < SPM_PAGESIZE/sizeof(awaiting); ++i)
		{
			// get low 7bits of 4 bytes
			UPDATER_CRC_BYTE
			awaiting[0] = b & 0x7f;
			UPDATER_CRC_BYTE
			awaiting[1] = b & 0x7f;
			UPDATER_CRC_BYTE
			awaiting[2] = b & 0x7f;
			UPDATER_CRC_BYTE
			awaiting[3] = b & 0x7f;

			// msbs of 4 bytes
			UPDATER_CRC_BYTE
			awaiting[0] |= (b & 1) << 7;
			awaiting[1] |= (b & 2) << 6;
			awaiting[2] |= (b & 4) << 5;
			awaiting[3] |= (b & 8) << 4;

			// copy to page
			page[byteIdx++] = awaiting[0];
			page[byteIdx++] = awaiting[1];
			page[byteIdx++] = awaiting[2];
			page[byteIdx++] = awaiting[3];
		}
		
		// check crc
		UPDATER_GET_BYTE
		crcSent = (b & 0x7f) << 9;
		UPDATER_GET_BYTE
		crcSent |= (b & 0x7f) << 2;
		UPDATER_GET_BYTE
		crcSent |= b & 0x03;
		
		if(crcSent != crc)
			break;
		
		// sysex termination
		UPDATER_WAIT_BYTE(0xf7)
		
		// spinning 7seg
		
		seg <<= 1;
		if(seg >= 0x40)
			seg=1;
		
		hardware_write(1,CSO1,seg);
		CYCLE_WAIT(8);

		// program page
//		blHack_program_page(pageIdx*STORAGE_PAGE_SIZE,page);
		boot_program_page(pageIdx*STORAGE_PAGE_SIZE,page);
	}
	
	// show 'S' or 'E' on the 7seg, depending on success or error
	hardware_write(1,CSO1,(success)?0x6d:0x79);

	// loop infinitely
	for(;;);
}

// override __init function to call updater, so that we can check if we need to go to update mode.
// if we don't, go back to the regular init process
// this function is in the vectors section to ensure it stays in the first SPM_PAGESIZE block of flash
void __attribute__((section(".vectors"),naked,used)) __init(void)
{
	asm volatile
	(
		// init status reg
		"clr r1 \n\t"
		"out 0x3f,r1 \n\t" // SREG
		// init stack
		"ldi r28,lo8(__stack) \n\t"
		"ldi r29,hi8(__stack) \n\t"
		"out 0x3e,r29 \n\t" // SPH
		"out 0x3d,r28 \n\t" // SPL
		// call updater
		"call 0x1e000 \n\t"
		// back to regular init
		"jmp __do_clear_bss \n\t"
	);
}

int main(void)
{
	CPU_PRESCALE(CPU_16MHz);  

#ifdef DEBUG
	// initialize the USB, and then wait for the host
	// to set configuration.  If the Teensy is powered
	// without a PC connected to the USB port, this 
	// will wait forever.
	usb_init();
	while (!usb_configured()) /* wait */ ;

	// wait an extra second for the PC's operating system
	// to load drivers and do whatever it does to actually
	// be ready for input
	_delay_ms(1000);

	print("p600firmware\n");
#endif

	// no interrupts while we init
	
	cli();
	
	// initialize low level

	hardware_init(1);

 // Enable NMI FlipFlop
	io_write(CS06, 0b00110001);

 // Just to be sure
//	SPI_test(); 
//	SPI_test_page();
	
	// initialize synth code

	synth_init();
	
	// all inited, enable ints and do periodical updates
	
	sei();
	
	for(;;)
	{
		synth_update();
	}
}

ISR(TIMER0_COMPA_vect)
{
	// use nested interrupts, because we must still handle synth_uartInterrupt
	// we need to ensure we won't try to recursively handle another synth_timerInterrupt!
	
	TIMSK0 &= ~(1 << OCIE0A); //Disable overflow interrupt for Timer0
	TIFR0 |= 7; // Clear any pending interrupt
	sei();

	synth_timerInterrupt();

	cli();
	TIMSK0 |= (1 << OCIE0A); //Re-enable overflow interrupt for Timer0
}

#ifdef UART_USE_HW_INTERRUPT
ISR(INT4_vect) 
#else
ISR(TIMER2_COMPA_vect) 
#endif
{ 
	synth_uartInterrupt();
}

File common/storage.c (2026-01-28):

////////////////////////////////////////////////////////////////////////////////
// Presets and settings storage, relies on low level page storage system
////////////////////////////////////////////////////////////////////////////////

#include "storage.h"
#include "uart_6850.h"
#include "synth.h"
#include "ui.h"
#include "math.h"
#include "midi.h"
#include "display.h"

// increment this each time the binary format is changed
#define STORAGE_VERSION 8

#define STORAGE_MAGIC 0x006116a5

#define SETTINGS_PAGE_COUNT 2 // due to the tuning data the settings are too large for one page, with version 8: 305 bytes (one page has 256 bytes)
#define SETTINGS_PAGE ((STORAGE_SIZE/STORAGE_PAGE_SIZE)-4)

#define STORAGE_MAX_SIZE (SETTINGS_PAGE_COUNT*STORAGE_PAGE_SIZE) // this is the buffer size, which must at least hold the settings data (see above)

const uint8_t steppedParameterRange[spCount] =
{
    /* Osc A Saw */ 2,
    /* Osc A Triangle */ 2,
    /* Osc A Square */ 2,
    /* Osc B Saw */ 2,
    /* Osc B Triangle */ 2,
    /* Osc B Sqr */ 2,
    /* Sync */ 2,
    /* Poly Mod Oscillator A Destination */ 2,
    /* Poly Mod Filter Destination */ 2,
    /* LFO Shape */ 3,
    /* Envelope Routing */ 4,
    /* LFO Mode Destination */ 4,
    /* Keyboard Filter Tracking */ 3,
    /* Filter Envelope Shape */ 2,
    /* Filter Envelope Fast/Slow */ 2,
    /* 2nd Envelope Shape */ 2,
    /* Unison */ 2,
    /* Assigner Priority Mode */ 3,
    /* Pitch bender semitones */ 4,
    /* Pitch bender target */ 5,
    /* LFO Sync */ 8,
    /* Osc pitch mode */ 3,
    /* Modulation wheel target */ 2,
    /* Vibrato target */ 2,
    /* 2nd Envelope Fast/Slow */ 2,
    /* PW Sync Bug */ 2,
    /* spCount */ 0,

};

struct settings_s settings;
struct preset_s currentPreset;

static struct
{
	uint8_t buffer[STORAGE_MAX_SIZE];
	uint8_t * bufPtr;
	uint8_t version;
} storage;

static uint32_t storageRead32(void)
{
	uint32_t v;
	v=*(uint32_t*)storage.bufPtr;
	storage.bufPtr+=sizeof(v);
	return v;
}

static uint16_t storageRead16(void)
{
	uint16_t v;
	v=*(uint16_t*)storage.bufPtr;
	storage.bufPtr+=sizeof(v);
	return v;
}

/*
static int16_t storageReadS16(void)
{
	int16_t v;
	v=*(int16_t*)storage.bufPtr;
	storage.bufPtr+=sizeof(v);
	return v;
}
*/

static uint8_t storageRead8(void)
{
	uint8_t v;
	v=*(uint8_t*)storage.bufPtr;
	storage.bufPtr+=sizeof(v);
	return v;
}

static int8_t storageReadS8(void)
{
	int8_t v;
	v=*(int8_t*)storage.bufPtr;
	storage.bufPtr+=sizeof(v);
	return v;
}

static void storageWrite32(uint32_t v)
{
	*(uint32_t*)storage.bufPtr=v;
	storage.bufPtr+=sizeof(v);
}

static void storageWrite16(uint16_t v)
{
	*(uint16_t*)storage.bufPtr=v;
	storage.bufPtr+=sizeof(v);
}

/*
static void storageWriteS16(int16_t v)
{
	*(int16_t*)storage.bufPtr=v;
	storage.bufPtr+=sizeof(v);
}
*/

static void storageWrite8(uint8_t v)
{
	*(uint8_t*)storage.bufPtr=v;
	storage.bufPtr+=sizeof(v);
}

static void storageWriteS8(int8_t v)
{
	*(int8_t*)storage.bufPtr=v;
	storage.bufPtr+=sizeof(v);
}

static void resetPickUps(void)
{
    uint8_t cnt;
    for (cnt=0;cnt<cpCount;++cnt) currentPreset.contParamPotStatus[cnt]=0;
}

static LOWERCODESIZE int8_t storageLoad(uint16_t pageIdx, uint8_t pageCount)
{
	uint16_t i;
	
	for (i=0;i<pageCount;++i)
		storage_read(pageIdx+i,&storage.buffer[STORAGE_PAGE_SIZE*i]);
	
	storage.bufPtr=storage.buffer;
	storage.version=0;

	if(storageRead32()!=STORAGE_MAGIC)
	{
#ifdef DEBUG
		print("Error: bad page: "); 
		phex(pageIdx);
		print("\n");
#endif	
		memset(storage.buffer,0,sizeof(storage.buffer));
		return 0;
	}

	storage.version=storageRead8();
	
	return 1;
}

static LOWERCODESIZE void storagePrepareStore(void)
{
	memset(storage.buffer,0,sizeof(storage.buffer));
	storage.bufPtr=storage.buffer;
	storage.version=STORAGE_VERSION;
	
	storageWrite32(STORAGE_MAGIC);
	storageWrite8(storage.version);
}

static LOWERCODESIZE void storageFinishStore(uint16_t pageIdx, uint8_t pageCount)
{
	if((storage.bufPtr-storage.buffer)>sizeof(storage.buffer))
	{
#ifdef DEBUG
		print("Error: writing too much data to storage !\n"); 
#endif	
		return;
	}
	
	uint16_t i;
	
	for (i=0;i<pageCount;++i)
		storage_write(pageIdx+i,&storage.buffer[STORAGE_PAGE_SIZE*i]);
}

LOWERCODESIZE int8_t settings_load(void)
{
	int8_t i,j;
	
	BLOCK_INT
	{
		if (!storageLoad(SETTINGS_PAGE,SETTINGS_PAGE_COUNT))
			return 0;

		// defaults

		settings.voiceMask=0x3f;
		settings.vcfLimit=0;
		settings.seqArpClock=HALF_RANGE;
		settings.presetNumber=1; // if no other info, set selected preset to 1
		settings.benderMiddle=HALF_RANGE;
		settings.presetMode=0; // if no info, default start up is in live mode
		settings.midiReceiveChannel=-1; // default is 'OMNI'
		settings.voiceMask=0x3f; // default is: all on
		settings.midiSendChannel=0; // default is: 1
		settings.syncMode=smInternal; // default is internal clock
		settings.vcfLimit=0; // default is: no limit on the VCF
		settings.midiMode=0; // normal mode
		settings.panelLayout=0; // GliGli layout

		if (storage.version<1)
			return 1;

		// v1

		for(j=0;j<TUNER_OCTAVE_COUNT;++j)
			for(i=0;i<TUNER_CV_COUNT;++i)
				settings.tunes[j][i]=storageRead16();

		settings.presetNumber=storageRead16();
		// ensure that preset channel is valid, default to 0:
		if (settings.presetNumber>99) settings.presetNumber=0;
	    settings.benderMiddle=storageRead16();
		settings.presetMode=storageRead8();
		// ensure that MIDI channel is valid to void array out of bounds problems:
		settings.midiReceiveChannel=storageReadS8();
		if (settings.midiReceiveChannel<-1) settings.midiReceiveChannel=-1;
		if (settings.midiReceiveChannel>15) settings.midiReceiveChannel=15;

		if (storage.version<2)
			return 1;

		// v2

		settings.voiceMask=storageRead8();
		// ensure that MIDI channel is valid to void array out of bounds problems:
		settings.midiSendChannel=storageReadS8();	     
		if (settings.midiSendChannel<0) settings.midiSendChannel=0;
		if (settings.midiSendChannel>15) settings.midiSendChannel=15;
		
		if (storage.version<3)
			return 1;

		// v3
		
		settings.syncMode=storageRead8();
	
		if (storage.version<4)
			return 1;
		
		// v4
		
		i=storageRead8(); // this used to be "Spread" move to patch with V8 - need to read and ignore it

		if (storage.version<5)
			return 1;

		// v5
		
		settings.vcfLimit=storageReadS8();

		if (storage.version<6)
			return 1;

		// v6
		
		settings.seqArpClock=storageRead16();

		if (storage.version<8)
        {
			return 1;
        }

		// v8

		settings.midiMode=storageRead8();
        settings.midiMode=(settings.midiMode>1)?0:settings.midiMode;

		settings.panelLayout=storageRead8();
        settings.panelLayout=(settings.panelLayout>1)?0:settings.panelLayout;

	}
	
	return 1;
}
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

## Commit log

2026-01-28 Imogen original file
    [midi_cc_map.ods, new_ui.ods, sysex_format.ods]
2026-01-28 PCB files
    [Z80P600.csv, Z80P600.kicad_pcb, Z80P600.kicad_sch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]

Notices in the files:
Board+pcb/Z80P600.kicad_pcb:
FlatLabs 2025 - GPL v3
